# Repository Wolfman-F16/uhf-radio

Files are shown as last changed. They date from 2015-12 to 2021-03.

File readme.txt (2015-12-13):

This file is part of uhf-radio.
This project is hosted on github.com/Wolfman-F16
uhf-radio uses v-usb, which comes with its own GPL v2 license (see /usbdrv/license.txt).

    uhf-radio is free software: you can redistribute it and/or modify
    it under the terms of the GNU General Public License as published by
    the Free Software Foundation, either version 2 of the License, or
    any later version.

    uhf-radio is distributed in the hope that it will be useful,
    but WITHOUT ANY WARRANTY; without even the implied warranty of
    MERCHANTABILITY or FITNESS FOR A PARTICULAR PURPOSE.  See the
    GNU General Public License for more details.

    You should have received a copy of the GNU General Public License
    along with uhf-radio.  If not, see <http://www.gnu.org/licenses/>.

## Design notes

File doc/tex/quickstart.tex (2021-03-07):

\documentclass[12pt, a4paper]{report}

\usepackage[top=15mm, bottom=20mm, left=25mm, right=30mm]{geometry}
\usepackage[english]{babel}
\usepackage{verbatim}
\usepackage{lastpage}

\usepackage{longtable}
\usepackage{fancyhdr}
\usepackage{graphicx}
\usepackage{xcolor}

\fancypagestyle{plain} {
\renewcommand{\headrulewidth}{0pt}
	\fancyhf{}
	\fancyfoot[l]{
		\today
	}
	\fancyfoot[c]{
		v 1.2.0
	}
	\fancyfoot[r]{
		\thepage\slash \pageref*{LastPage}
	}
}

\usepackage[pdfauthor=Wolfman,pdftitle=UHF Radio,bookmarks]{hyperref}

%----------------------------------------------------------------  BEGIN OF DOCUMENT ---------------------------------------------------------------- 
\begin{document}

\title{UHF Electronics Quickstart Guide\\\large Electronics for UHF ARC-164 Airborne Radio Panel}
\author{Wolfgang ''Wolfman'' Engelhard }
\maketitle

% ---------------------------------------------------------------- history
\pagestyle {plain}

\section{Revision History}
\begin{itemize}
\item[1.0.3]
Page 5 updated
\item[1.1.0]
Pages 4,11,12 updated
\item[1.2.0]
Pages 11, 12 updated, minor clarifications in pages 13 to 15. Changed to \LaTeX
\end{itemize}•

% ---------------------------------------------------------------- disclaimer
\section{Disclamer}
This document is for information only. It may not be accurate, nor free of errors. It has been created with the best of my knowledge, but no liability is assumed for any damage caused by using this document or the devices described herein.

% ---------------------------------------------------------------- viperpits
\section{viperpits.org}
A lot of information is also available on the viperpits.org forum. If you want to know about the history of this development read the thread
\href{http://www.viperpits.org/smf/index.php?topic=5082.0}{viperpits.org UHF electronics}
(free registration required)

% ---------------------------------------------------------------- PARTLIST ---------------------------------------------------------------- 
\chapter{Partlist}
\begin{itemize}
\item[1x]
UHF Indication Board
\item[1x]
UHF Control Board
\item[1x]
UHF ARC-164 Panel
\item[1x]
5V\slash 1A power supply (an additional 5V\slash1.5A power supply if using backlight!)
\item[1x]
10pol flat wire connector cable
\item[1x]
2pol wire cable (already mounted)
\item[1x]
7-segment LED board
\item[1x]
Headphones or high ohm loudspeaker (not shown)
\end{itemize}•

\begin{figure}[h!tb]

\caption{Parts}
\end{figure}

% ---------------------------------------------------------------- Components
\section{Bill Of Material}
\framebox[\textwidth]{
\parbox{0.9\textwidth}{
Note:\newline I do not endorse buying from mouser, the intention is only to give reference.
}
}

\subsection{PCB}
The eagle\footnote{cadsoft.de} .brd files can be used to generate gerber files if your local PCB manufacturer does not accept eagle files.

% ---------------------------------------------------------------- Indication board partlist
\subsection{UHF Indication Board}
\begin{longtable}{ *{5}{| l } | }
\hline
\textbf{Article} & \textbf{Value} & \textbf{Type} & \textbf{\#} & \textbf{Mouser order number} \\
\hline
\endhead
ATMega8 & DIL-28 & IC & 1 & 556-ATMEGA8A-PU \\
Shift Register 595 & DIL-16 & IC & 8 & 511-M74HC595 \\
Quarz 16 Mhz & HC18U-V & Quarz & 1 & 815-ABL-16-B2 \\
IC-sockel (opt.) & 16 pol & Sockel & 8 & 517-4816-3000-CP \\
IC-sockel (opt.) & 28 pol & Sockel & 1 & 517-4828-3004-CP \\
LED yellow & 1206 & Led & 1 & 696-SML-LX1206YC \\
2V7 Z-Diode 1,3W & DO-204AL & Diode & 1 & 771-BZX79-C2V7133 \\
BC141 & TO-39 & Transistor & 1 & 511-BC141-16 \\
SMCC 10uH &  & Inductivity & 1 & 434-23-100 \\
100nF & RM5 & Capacitor & 4 & 80-C320C104K5R5CA \\
10nF & RM2.5 & Capacitor & 2 & 80-C315C103K5R5CA \\
1nF & RM2.5 & Capacitor & 1 & 80-C315C102K5R5CA \\
100pF & RM2.5 & Capacitor & 2 & 80-C315C101K5R5CA \\
22pF  & RM2.5 & Capacitor & 2 & 80-C315C220K5G5CA \\
150R & 805 & Resistor & 9 & 652-CR0805FX-1500ELF \\
8k2 & 805 & Resistor & 1 & 652-CR0805FX-8201ELF \\
180R & 1/4W & Resistor & 1 & 291-180-RC \\
560R & 1/4W & Resistor & 1 & 291-560-RC \\
10R & 5W & Resistor & 1 & 284-ACS5SW-10 \\
Powerplug & AK500/3 & Connector & 1 & 845-34.103 \\
Pinheader 10pol & 5x2 & Connector & 1 & 517-D2510-6002-AR \\
Pinheader 3pol & 3 pol & Connector & 1 & 855-M20-9730345 \\
Pinheader 8pol & 8 pol & Connector & 8 & 855-M20-9730846 \\
Poti 47k & RM2.54 & Poti & 1 & 652-3296Y-1-473LF \\
\hline
\caption {UHF Indication Board}
\end{longtable}

\framebox[\textwidth]{
\parbox{0.9\textwidth}{
Note:\par Instead of the Poti you could just as well mount a 3pol pinheader and connect any potentiometer with about the same resistor value.
}
}

% ---------------------------------------------------------------- Control board partlist
\subsection{UHF Control Board RP}
\begin{longtable}{ *{5}{| l } | }
\hline
\textbf{Article} & \textbf{Value} & \textbf{Type} & \textbf{\#} & \textbf{Mouser order number} \\
\hline
\endhead
ATMega8 & DIL-28 & IC & 1 & 556-ATMEGA8A-PU \\
22pF & RM2.5 & Capacitor & 2 & 80-C315C220K5G5CA \\
100pF & RM2.5 & Capacitor & 2 & 80-C315C101K5R5CA \\
10nF & RM2.5 & Capacitor & 2 & 80-C315C103K5R5CA \\
10nF & RM5 & Capacitor & 1 &  \\
100nF & RM5 & Capacitor & 2 & 80-C320C104K5R5CA \\
10uF El.Ca. & RM2.5 & Capacitor & 1 & 647-UST1H100MDD1TE \\
100uF El.Ca. & RM2.5 & Capacitor & 1 & 647-UVR1V101MED1TA \\
Audio Jack  & 3.5mm & Connector & 1 & 502-35RAPC4BH3 \\
Sockets 14pol & 14pol & Connector & 4 &  \\
Sockets 11pol & 11pol & Connector & 2 &  \\
Powerplug & A500/2 & Connector & 2 & 845-34.102 \\
Pinheader 3pol & 3 pol & Connector & 2 & 855-M20-9730345 \\
USB -B &  & Connector & 1 & 649-61729-0010BLF \\
Pinheader 6pol & 2x3 & Connector & 1 & 517-D2510-6002-AR \\
Pinheader 6pol & 3 pol & Connector & 2 & 855-M20-9730345 \\
3,3V Z-Diode Fast 0,5W & DO35 & Diode & 2 & 78-BZX55B3V3 \\
1N4148 & MINIMELF & Diode & 22 & 78-LL4148 \\
74HC154 & SO24W & IC & 1 & 771-74HC4515D \\
ATMega16 & DIL-40 & IC & 1 & 556-ATMEGA16A-PU \\
10uH & SMC & Inductivity & 1 & 434-23-100 \\
LED yellow & 1206 & Led & 1 & 696-SML-LX1206YC \\
16Mhz & HC18U-V & Quarz & 1 & 815-ABL-16-B2 \\
2k2 & 805 & Resistor & 1 & 652-CR0805FX-2201ELF \\
220R & 805 & Resistor & 1 & 652-CR0805FX-2200ELF \\
4k7 & 805 & Resistor & 1 & 652-CR0805FX-4701ELF \\
820R & 1/4W & Resistor & 1 & 291-820-RC \\
82R & 805 & Resistor & 2 & 652-CR0805FX-82R0ELF \\
8k2 & 805 & Resistor & 1 & 652-CR0805FX-8201ELF \\
150R & 805 & Resistor & 4 & 652-CR0805FX-1500ELF \\
IC-Sockel (opt.) & 40pol & Sockel & 1 & 517-4840-6000-CP \\
BC327 & TO-92 & Transistor & 1 & 512-BC32740BU \\
BC337 & TO-92 & Transistor & 1 & 512-BC33740BU \\
\hline
\caption {UHF Control Board RP}
\end {longtable}

% ---------------------------------------------------------------- other partlist
\subsection{Additional Components}
\begin{longtable}{ *{5}{| l } | }
\hline
\textbf{Article} & \textbf{Value} & \textbf{Type} & \textbf{\#} & \textbf{Mouser order number} \\
\hline
\endhead
ATMega8 & DIL-28 & IC & 1 & 556-ATMEGA8A-PU \\
Flat wire cable connector & AWG28 & Wire & 1 & 517-2M-BDBD-016-12 \\
Jumper wire & 2pol & Wire & 1 &  \\
7-Segment LED Com. Anode & RM2.54 & LED & 8 & 630-HDSP-7801-JK000 \\
Black wire 0.14mm² &  & Wire &  &  \\
Socket 8pol & RM2.54 & Connector & 8 &  \\
Prototype Board 160x100 & RM2.54 & PCB & 1 &  \\
Socket 5pol 5mm height & RM2.54 & Connector & 16 &  \\
\hline
\caption {Additional components}
\end {longtable}

% ----------------------------------------------------------------  ASSEMBLY ---------------------------------------------------------------- 
\chapter{Assembly}
% ---------------------------------------------------------------- wiring
\section{Wiring the 7-segment LED \emph{HDSP-7801-JK000}}

In case you use the 7-Segment LED Avago \emph{HDSP-7801-JK000}, you can use the following table to wire the devices.

\begin{table}[ht]
\centering
\begin{tabular}{ *{3}{| l } | }
\hline
\textbf{UHF Indication Board Pin} & \textbf{Segment} & \textbf{HDSP-7801-JK000 Pin} \\
\hline
1 (lilac) & a & 10 \\
\hline
2 (blue) & b & 9 \\
\hline
3 (green) & c & 8 \\
\hline
4 (yellow) & d & 5 \\
\hline
5 (orange) & e & 4 \\
\hline
6 (red) & f & 2 \\
\hline
7 (brown) & g & 3 \\
\hline
8 (black) & DP & 7 \\
\hline
Common Anode &   & 6 \&{} 1 \\
\hline
\end{tabular}
\caption {Wiring}
\end {table}
\label{Table4}

\begin{figure}[h!tb]
\centering

\caption{7-Segment LED layout}
\end{figure}

There are ready made connectors\footnote{\parbox{105mm}{\href{http://www.reichelt.de/Platinen-Steckverbinder/PS-25-8G-WS/3//index.html?ACTION=3\&GROUPID=5216\&ARTICLE=14831\&SHOW=1\&START=0\&OFFSET=500\&}{reichelt.de PS-25-8G-WS}}} available that use colored wires. These match the colors given for the UHF Indication Board Pin in Table \ref{Table4}. 

Connect all Common Anode pins to a common (preferably red) wire.

The LEDs should be soldered to small prototype boards that fit into the tiny space of the UHF panel. Sockets do not provide reliable contact.
Mount the 7-Segment LED Board to the UHF ARC-164 Panel. M2.5 screws fit through the UHF panel holes.

% ---------------------------------------------------------------- Board assembly
\section{Assembly of UHF Control Board and UHF Indication Board}
\emph{TODO}

\emph{
Note: \\ The preferred  way to mount the boards would be in a 90 degree angle to the UHF panel. This allows use of short wires for all connections. A casing, like the real panel could be build to mount the boards with spacers to the sidewalls.
}

% ---------------------------------------------------------------- CONNECTIONS ---------------------------------------------------------------- 
\chapter{Connections}
% ---------------------------------------------------------------- 
\section{If you have only the UHF Indication Board}
\begin{enumerate}
\item
Connect the UHF Indication Board with the 5V Powersupply. The polarity is printed on the PCB.
\item
Connect the 7-Segment LED Board to the UHF Indication Board.
\end{enumerate}•

\begin{figure}[h!tb]
\centering

\caption{Pin 1}
\end{figure}

The UHF Indication Board Pin 1 is at the same position for all connectors.
The common anode wire is connected to the power plug labeled "PWM".

The 7-seg. LEDs are assigned as shown in figure \ref{fig:ledConn}
\begin{figure}[h!]
\centering

\caption{PCB to Display Connection}
\label{fig:ledConn}
\end{figure}

% ---------------------------------------------------------------- 
\section{If you have both the UHF Indication Board and the UHF Control Board}

\begin{enumerate}
\item
Do the connections for the UHF Indication Board as instructed in the previous chapter.
\item
Connect the Volume knob pinheader to a potentiometer with the 2pol wire cable. 

\framebox[\textwidth]{
\parbox{0.9\textwidth}{
Note: \newline
The UHF Control Board can use the Volume knob of the UHF ARC-164 Panel to adjust volume.
Use the 2pol wire cable to connect the Volume knob pinheader to the audio volume pinheader of the UHF Control Board. (see figure \ref{fig:volPoti})
}
}

\begin{figure}[h!t]
\centering

\caption{Volume Potentiometer Connection}
\label{fig:volPoti}
\end{figure}

\item
Connect the UHF Control Board to the UHF ARC-164 Panel. The wiring is 1:1 when the board faces the panel (see also labeling J1 and J2 on both board and panel).

\begin{figure}[h!t]
\centering

\caption{Control Board Connection}
\label{fig:brdConn}
\end{figure}

\item
Connect the UHF Indication Board and the UHF Control Board with the 10pol flat wire cable.

\item
Connect Headphones to the UHF Control Board.
\item
UHF panel backlight power supply
The powersupply for the UHF Panel backlight is connected to the UHF Control Board (The Power Plug labelled "Backlight" in figure \ref{fig:volPoti}).

\item
UHF Control Board power supply, USB not connected
The power plug "Power Supply" for the UHF Control Board (see figure \ref{fig:volPoti}) should be left unconnected. The board receives its power through the UHF Indication Board.

\framebox[\textwidth]{
\parbox{0.9\textwidth}{\large\color{red}
\textsc{Warning:}\newline
Do \textsc{not} connect the UHF Control Board to the USB port for power supply!
Always connect the UHF Indication Board with a power supply!
}
}

\item
UHF Control Board power supply, USB connected
Connect a standard USB-B cable to the UHF Control Board.
The USB port provides power for the UHF Control Board, to avoid damaging your USB port, break the 1st wire of the 10pol flat wire cable. The power plug "Power supply" is for debugging purposes only.

\end{enumerate}•

% ---------------------------------------------------------------- TTL 
\section{If you have a TTL USART device}
Both boards have a serial interface operating on TTL voltage. The transmit pin is labeled "T", The receive pin is labeled "R" and the ground pin is labeld "G". Connect a RS232-TTL or USB-TTL converter for accessing terminal operations. The baud rate is 38400.

% ---------------------------------------------------------------- OPERATION ----------------------------------------------------------------
\chapter{Operation}
% ---------------------------------------------------------------- Switch on
\section{Power On}
The LEDs should display a test pattern for about a second, then show a channel number and a frequency.
The status LED on the UHF Indication Board should be briefly on.
The UHF Indication Board has a potentiometer to adjust brightness. Adjust as preferred.

% ---------------------------------------------------------------- usage
\section {Usage}
The operation of the UHF radio is documented in this PDF file.

\href{http://mayprinting.com/TSB/data/comm/arc-164.pdf}{http://mayprinting.com/TSB/data/comm/arc-164.pdf}\footnote{This link does not work anymore.}

\noindent
The TSS/RSG frequency is 310.425. Use this frequency to get a Tone.

% ---------------------------------------------------------------- USB
\section{USB Keyboard}
The UHF Control Board operates as a USB keyboard.

The Squelch switch in position ON suppresses sending keystrokes, so make sure it is in the correct position.

A prototype USB vendor and product ID are used, so use at your own risk!
The following switches send key strokes

\begin{longtable}{ *{2}{| l } | }
\hline
\textbf{Operator} & \textbf{Key} \\
\hline
\endhead
Mode Selector OFF & SHF ALT ENTER \\
Mode Selector MAIN & ALT CTRL ENTER \\
Mode Selector BOTH & SHF ALT CTRL ENTER \\
Mode Selector ADF & SHF CTRL Z \\
MPG MNL & SHF ALT CTRL X \\
MPG PRESET & SHF CTRL C \\
MPG GRD & SHF ALT C \\
CHAN INC & SHF ALT S \\
CHAN DEC & ALT CTRL S \\
FREQ 1 2 & SHF ALT D \\
FREQ 1 3 & ALT CTRL D \\
FREQ 1 A & SHF CTRL D \\
FREQ 2 0 & SHF ALT CTRL D \\
FREQ 2 1 & SHF CTRL F \\
FREQ 2 2 & SHF ALT F \\
FREQ 2 3 & ALT CTRL F \\
FREQ 2 4 & SHF ALT CTRL M \\
FREQ 2 5 & SHF CTRL G \\
FREQ 2 6 & SHF ALT G \\
FREQ 2 7 & ALT CTRL G \\
FREQ 2 8 & SHF ALT CTRL G \\
FREQ 2 9 & SHF CTRL H \\ 
FREQ 3 0 & SHF ALT H \\
FREQ 3 1 & ALT CTRL H \\
FREQ 3 2 & SHF ALT CTRL H \\
FREQ 3 3 & SHF CTRL J \\
FREQ 3 4 & SHF ALT J \\
FREQ 3 5 & ALT CTRL J \\
FREQ 3 6 & SHF ALT CTRL J \\
FREQ 3 7 & SHF CTRL K \\
FREQ 3 8 & SHF ALT K \\ 
FREQ 3 9 & ALT CTRL K \\
FREQ 4 0 & SHF ALT CTRL K \\
FREQ 4 1 & SHF CTRL L \\
FREQ 4 2 & SHF ALT L \\
FREQ 4 3 & ALT CTRL L \\
FREQ 4 4 & SHF ALT CTRL L \\
FREQ 4 5 & SHF CTRL ; \\
FREQ 4 6 & SHF ALT ; \\
FREQ 4 7 & ALT CTRL ; \\
FREQ 4 8 & SHF ALT CTRL ; \\
FREQ 4 9 & SHF CTRL ' \\
FREQ 5 00 & SHF ALT ' \\
FREQ 5 25 & ALT CTRL ` \\
FREQ 5 50 & SHF ALT CTRL ` \\
FREQ 5 75 & SHF CTRL ENTER \\
\hline
\caption {Key Assignment}
\end {longtable}
\begin{comment}
These are not supported yet in source code and Falcon BMS
LOAD & SHF CTRL S \\
STATUS & SHF ALT CTRL S \\
Zero On & ALT CTRL A \\
Zero Off & SHF ALT CTRL A \\
Squelch On & SHF ALT X \\
Squelch Off & ALT CTRL X \\
Tone T & SHF ALT Z \\
Tone TONE & ALT CTRL Z \\
CH Vol Inc & SHF ALT CTRL Z \\
CH Vol Dec & SHF CTRL X \\
TEST & SHF ALT . \\
\end{comment}

% ---------------------------------------------------------------- shared  mem
\section {Connecting to Falcon BMS Shared Memory}

With firmware version 23 an newer (see chapter Operation on how to check the version), the UHF radio supports synchronising with the shared memory. A shared memory reader is required to establish the data transfer and is available at github\footnote{github.com/Wolfman-F16/uhfRadioUsbSharedMemReader}. 
To allow data transfer to a USB Keyboard (that is what the UHF radio basically is for a Windows OS), installation of a filter is required. 
The software to do so is available at \href{http://sourceforge.net/projects/libusb-win32/}{libusb-win32}.
Type \begin{quote}\emph{install-filter install –device=USBVid\_16c0.Pid\_27db.Rev\_0100} \end{quote} on the commandline. Or use the \emph{install-filter-gui.exe} to do the same. This must be done only a single time.
Start the commandline tool \emph{uhfRadio.exe} and data will be sent, once the shared memory is available.

\framebox[\textwidth]{
\parbox{0.9\textwidth}{
Note: \newline
Before ramp start, set the UHF radio rotary switches to channel 6 and frequency 225.000
}
}

\framebox[\textwidth]{
\parbox{0.9\textwidth}{
Note: \newline
During Falcon BMS ramp/taxi/takeoff loading screen, the channel and frequency often show wierd numbers for a brief time.
}
}

\framebox[\textwidth]{
\parbox{0.9\textwidth}{
Note: \newline
If channel or frequency is out of sync, use the squelch switch to suppress sending key strokes.
}
}

% ---------------------------------------------------------------- MAINTENANCE ----------------------------------------------------------------
\chapter{Maintenance}
% ---------------------------------------------------------------- Firmware
\section{Firmware Version}
The software version of the UHF Control Board can be displayed by switching to ADF and switching the T-Tone switch to T.

The current firmware version as of writing this document is v28.

\section{Firmware Update}
The UHF Control Board supports firmware update via USB. Before being able to use the USB firmware update, the USB bootloader\footnote{\href{}{github.com/Wolfman-F16/usbBootloader}} has to be flashed onto the UHF Control Board microcontroller.
To put the UHF Control Board in USB bootloader mode, 
\begin{enumerate}
\item
disconnect the UHF radio from power (incl. USB)
\item
 switch to ADF
 \item
 power up the UHF radio again.
\end{enumerate}•
Use the commandline tool \emph{avrusbboot.exe}\footnote{\href{}{github.com/Wolfman-F16/usbBootloaderCommander}} to upload the new firmware.
When the firmware upload is complete, put the UHF radio in normal operating mode by
\begin{enumerate}
\item
 disconnect the UHF radio from power (incl. USB)
 \item
switch to UHF OFF
\item
power up the UHF radio again.
\end{enumerate}•

% ---------------------------------------------------------------- Known Issues
\section{Known Issues}
\begin{itemize}
\item[]
TOD update and initiation of individual TOD not implemented, because there is no other radio that can be queried for a valid Tone signal (see also arc-164.pdf: 4-20 to 4-22).
\item[]
The FMT CHG text is not displayed after 5 seconds of inactivity in FMT.CHG mode.
\item[]
No interface to Falcon 4.0, Falcon 4 Allied Force or OpenFalcon4.7 is implemented, because non of them support UHF ARC-164 radio operations. 
However, Falcon BMS 4.32 provides limited support of UHF ARC-164 radio operations, extraction of display data is supported since Falcon BMS 4.33.
\item[]
The UHF panel volume knob cannot be used to control anything in Falcon BMS.
\item[]
The UHF Indication Board, when operated stand alone, might always show the LED test. Connect 5V to the pin SS (6) to solve this.
\item[]
If you think you found an error in this document or the software, please post at this forum thread
\href{http://www.viperpits.org/smf/index.php?topic=5082.0}{viperpits.org UHF electronics}
But remember the RTFM rule, so you might want to check the \emph{arc164.pdf} file thoroughly first.
\end{itemize}•

\tableofcontents

\end{document}

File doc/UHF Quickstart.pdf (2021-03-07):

# UHF Electronics Quickstart Guide

### Electronics for UHF ARC-164 Airborne Radio Panel

### Wolfgang ”Wolfman” Engelhard

### March 7, 2021

## 0.1 Revision History

1.0.3 Page 5 updated

1.1.0 Pages 4,11,12 updated

1.2.0 Pages 11, 12 updated, minor clarifications in pages 13 to 15. Changed to LATEX

## 0.2 Disclamer

This document is for information only. It may not be accurate, nor free of errors. It has been created with the best of my knowledge, but no liability is assumed for any damage caused by using this document or the devices described herein.

## 0.3 viperpits.org

A lot of information is also available on the viperpits.org forum. If you want to know about the history of this development read the thread viperpits.org UHF electronics (http://www.viperpits.org/smf/index.php?topic=5082.0) (free registration required)

March 7, 2021 | v 1.2.0 | 1/16

# Chapter 1

# Partlist

1x UHF Indication Board

1x UHF Control Board

1x UHF ARC-164 Panel

1x 5V/1A power supply (an additional 5V/1.5A power supply if using backlight!)

1x 10pol flat wire connector cable

1x 2pol wire cable (already mounted)

1x 7-segment LED board

1x Headphones or high ohm loudspeaker (not shown)

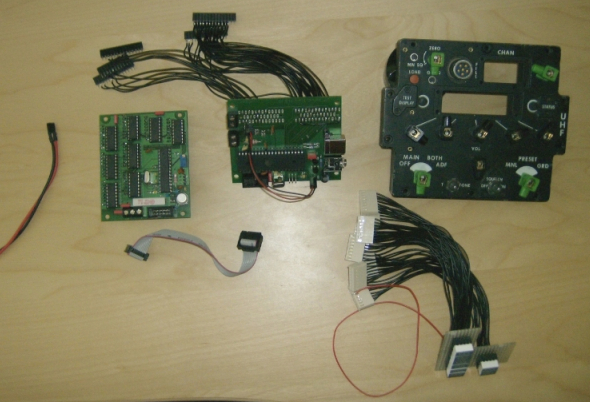
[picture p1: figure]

Figure 1.1: Parts

## 1.1 Bill Of Material

Note:
I do not endorse buying from mouser, the intention is only to give reference.

### 1.1.1 PCB

The eagle¹
.brd files can be used to generate gerber files if your local PCB manufacturer does not accept eagle files.

### 1.1.2 UHF Indication Board

Article | Value | Type | # | Mouser order number
ATMega8 | DIL-28 | IC | 1 | 556-ATMEGA8A-PU
Shift Register 595 | DIL-16 | IC | 8 | 511-M74HC595
Quarz 16 Mhz | HC18U-V | Quarz | 1 | 815-ABL-16-B2
IC-sockel (opt.) | 16 pol | Sockel | 8 | 517-4816-3000-CP
IC-sockel (opt.) | 28 pol | Sockel | 1 | 517-4828-3004-CP
LED yellow | 1206 | Led | 1 | 696-SML-LX1206YC
2V7 Z-Diode 1,3W | DO-204AL | Diode | 1 | 771-BZX79-C2V7133
BC141 | TO-39 | Transistor | 1 | 511-BC141-16
SMCC 10uH | | Inductivity | 1 | 434-23-100
100nF | RM5 | Capacitor | 4 | 80-C320C104K5R5CA
10nF | RM2.5 | Capacitor | 2 | 80-C315C103K5R5CA
1nF | RM2.5 | Capacitor | 1 | 80-C315C102K5R5CA
100pF | RM2.5 | Capacitor | 2 | 80-C315C101K5R5CA
22pF | RM2.5 | Capacitor | 2 | 80-C315C220K5G5CA
150R | 805 | Resistor | 9 | 652-CR0805FX-1500ELF
8k2 | 805 | Resistor | 1 | 652-CR0805FX-8201ELF
180R | 1/4W | Resistor | 1 | 291-180-RC
560R | 1/4W | Resistor | 1 | 291-560-RC
10R | 5W | Resistor | 1 | 284-ACS5SW-10
Powerplug | AK500/3 | Connector | 1 | 845-34.103
Pinheader 10pol | 5x2 | Connector | 1 | 517-D2510-6002-AR
Pinheader 3pol | 3 pol | Connector | 1 | 855-M20-9730345
Pinheader 8pol | 8 pol | Connector | 8 | 855-M20-9730846
Poti 47k | RM2.54 | Poti | 1 | 652-3296Y-1-473LF
Table 1.1: UHF Indication Board

Note:
Instead of the Poti you could just as well mount a 3pol pinheader and connect any potentiometer with about the same resistor value.

### 1.1.3 UHF Control Board RP

Article | Value | Type | # | Mouser order number
ATMega8 | DIL-28 | IC | 1 | 556-ATMEGA8A-PU
22pF | RM2.5 | Capacitor | 2 | 80-C315C220K5G5CA
100pF | RM2.5 | Capacitor | 2 | 80-C315C101K5R5CA

1
cadsoft.de

Article | Value | Type | # | Mouser order number
10nF | RM2.5 | Capacitor | 2 | 80-C315C103K5R5CA
10nF | RM5 | Capacitor | 1
100nF | RM5 | Capacitor | 2 | 80-C320C104K5R5CA
10uF El.Ca. | RM2.5 | Capacitor | 1 | 647-UST1H100MDD1TE
100uF El.Ca. | RM2.5 | Capacitor | 1 | 647-UVR1V101MED1TA
Audio Jack | 3.5mm | Connector | 1 | 502-35RAPC4BH3
Sockets 14pol | 14pol | Connector | 4
Sockets 11pol | 11pol | Connector | 2
Powerplug | A500/2 | Connector | 2 | 845-34.102
Pinheader 3pol | 3 pol | Connector | 2 | 855-M20-9730345
USB -B | | Connector | 1 | 649-61729-0010BLF
Pinheader 6pol | 2x3 | Connector | 1 | 517-D2510-6002-AR
Pinheader 6pol | 3 pol | Connector | 2 | 855-M20-9730345
3,3V Z-Diode Fast 0,5W | DO35 | Diode | 2 | 78-BZX55B3V3
1N4148 | MINIMELF | Diode | 22 | 78-LL4148
74HC154 | SO24W | IC | 1 | 771-74HC4515D
ATMega16 | DIL-40 | IC | 1 | 556-ATMEGA16A-PU
10uH | SMC | Inductivity | 1 | 434-23-100
LED yellow | 1206 | Led | 1 | 696-SML-LX1206YC
16Mhz | HC18U-V | Quarz | 1 | 815-ABL-16-B2
2k2 | 805 | Resistor | 1 | 652-CR0805FX-2201ELF
220R | 805 | Resistor | 1 | 652-CR0805FX-2200ELF
4k7 | 805 | Resistor | 1 | 652-CR0805FX-4701ELF
820R | 1/4W | Resistor | 1 | 291-820-RC
82R | 805 | Resistor | 2 | 652-CR0805FX-82R0ELF
8k2 | 805 | Resistor | 1 | 652-CR0805FX-8201ELF
150R | 805 | Resistor | 4 | 652-CR0805FX-1500ELF
IC-Sockel (opt.) | 40pol | Sockel | 1 | 517-4840-6000-CP
BC327 | TO-92 | Transistor | 1 | 512-BC32740BU
BC337 | TO-92 | Transistor | 1 | 512-BC33740BU
Table 1.2: UHF Control Board RP

### 1.1.4 Additional Components

Article | Value | Type | # | Mouser order number
ATMega8 Flat wire cable connector Jumper wire 7-Segment LED Com. Anode Black wire 0.14mm Socket 8pol Prototype Board 160x100 Socket 5pol 5mm height | DIL-28 AWG28 2pol RM2.54 RM2.54 RM2.54 RM2.54 | IC Wire Wire LED Wire Connector PCB Connector | 1 1 1 8 8 1 16 | 556-ATMEGA8A-PU 517-2M-BDBD-016-12 630-HDSP-7801-JK000

Table 1.3: Additional components

# Chapter 2

# Assembly

## 2.1 Wiring the 7-segment LED HDSP-7801-JK000

In case you use the 7-Segment LED Avago HDSP-7801-JK000, you can use the following table to wire the devices.

UHF Indication Board Pin | Segment | HDSP-7801-JK000 Pin
1 (lilac) | a | 10
2 (blue) | b | 9
3 (green) | c | 8
4 (yellow) | d | 5
5 (orange) | e | 4
6 (red) | f | 2
7 (brown) | g | 3
8 (black) | DP | 7
Common Anode | | 6 & 1

Table 2.1: Wiring

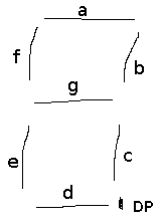
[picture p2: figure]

Figure 2.1: 7-Segment LED layout

There are ready made connectors¹ available that use colored wires. These match the colors given for the UHF Indication Board Pin in Table 2.1.
Connect all Common Anode pins to a common (preferably red) wire.
The LEDs should be soldered to small prototype boards that fit into the tiny space of the UHF panel. Sockets do not provide reliable contact. Mount the 7-Segment LED Board to the UHF ARC-164 Panel. M2.5 screws fit through the UHF panel holes.

1
reichelt.de PS-25-8G-WS (http://www.reichelt.de/Platinen-Steckverbinder/PS-25-8G-WS/3//index.html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)

## 2.2 Assembly of UHF Control Board and UHF Indication Board

TODO
Note:
The preferred way to mount the boards would be in a 90 degree angle to the UHF panel. This allows use of short wires for all connections. A casing, like the real panel could be build to mount the boards with spacers to the sidewalls.

# Chapter 3

# Connections

## 3.1 If you have only the UHF Indication Board

1. Connect the UHF Indication Board with the 5V Powersupply. The polarity is printed on the PCB.
2. Connect the 7-Segment LED Board to the UHF Indication Board.

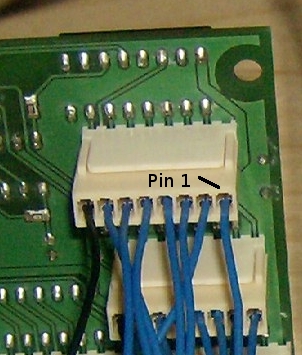
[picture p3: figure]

Figure 3.1: Pin 1

The UHF Indication Board Pin 1 is at the same position for all connectors. The common anode wire is connected to the power plug labeled ”PWM”.
The 7-seg. LEDs are assigned as shown in figure 3.2

## 3.2 If you have both the UHF Indication Board and the UHF Control Board

1. Do the connections for the UHF Indication Board as instructed in the previous chapter.
2. Connect the Volume knob pinheader to a potentiometer with the 2pol wire cable.

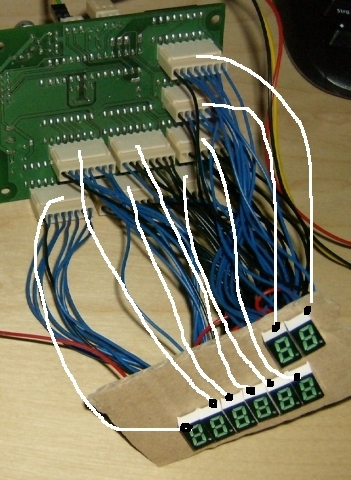
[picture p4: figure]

Figure 3.2: PCB to Display Connection

Note:
The UHF Control Board can use the Volume knob of the UHF ARC-164 Panel to adjust volume. Use the 2pol wire cable to connect the Volume knob pinheader to the audio volume pinheader of the UHF Control Board. (see figure 3.3)
3. Connect the UHF Control Board to the UHF ARC-164 Panel. The wiring is 1:1 when the board faces the panel (see also labeling J1 and J2 on both board and panel).
4. Connect the UHF Indication Board and the UHF Control Board with the 10pol flat wire cable.
5. Connect Headphones to the UHF Control Board.
6. UHF panel backlight power supply The powersupply for the UHF Panel backlight

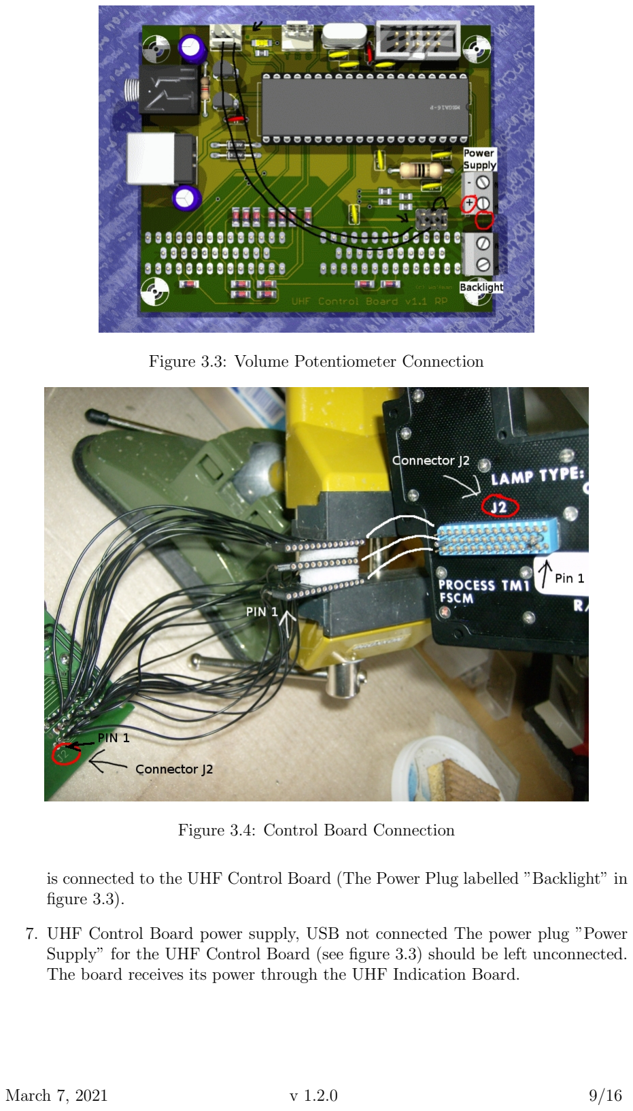
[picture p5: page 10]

Figure 3.3: Volume Potentiometer Connection

Figure 3.4: Control Board Connection

is connected to the UHF Control Board (The Power Plug labelled ”Backlight” in figure 3.3).

7. UHF Control Board power supply, USB not connected The power plug ”Power Supply” for the UHF Control Board (see figure 3.3) should be left unconnected. The board receives its power through the UHF Indication Board.

Warning:

### Do not connect the UHF Control Board to the USB port for power supply! Always connect the UHF Indication Board with a power supply!

8. UHF Control Board power supply, USB connected Connect a standard USB-B cable to the UHF Control Board. The USB port provides power for the UHF Control Board, to avoid damaging your USB port, break the 1st wire of the 10pol flat wire cable. The power plug ”Power supply” is for debugging purposes only.

## 3.3 If you have a TTL USART device

Both boards have a serial interface operating on TTL voltage. The transmit pin is labeled ”T”, The receive pin is labeled ”R” and the ground pin is labeld ”G”. Connect a RS232-TTL or USB-TTL converter for accessing terminal operations. The baud rate is 38400.

# Chapter 4

# Operation

## 4.1 Power On

The LEDs should display a test pattern for about a second, then show a channel number and a frequency. The status LED on the UHF Indication Board should be briefly on. The UHF Indication Board has a potentiometer to adjust brightness. Adjust as preferred.

## 4.2 Usage

The operation of the UHF radio is documented in this PDF file. http://mayprinting.com/TSB/data/comm/arc-164.pdf¹
The TSS/RSG frequency is 310.425. Use this frequency to get a Tone.

## 4.3 USB Keyboard

The UHF Control Board operates as a USB keyboard.
The Squelch switch in position ON suppresses sending keystrokes, so make sure it is in the correct position.
A prototype USB vendor and product ID are used, so use at your own risk! The following switches send key strokes
Operator | Key
Mode Selector OFF | SHF ALT ENTER
Mode Selector MAIN | ALT CTRL ENTER
Mode Selector BOTH | SHF ALT CTRL ENTER
Mode Selector ADF | SHF CTRL Z
MPG MNL | SHF ALT CTRL X
MPG PRESET | SHF CTRL C
MPG GRD | SHF ALT C
CHAN INC | SHF ALT S
CHAN DEC | ALT CTRL S
FREQ 1 2 | SHF ALT D
FREQ 1 3 | ALT CTRL D
FREQ 1 A | SHF CTRL D
FREQ 2 0 | SHF ALT CTRL D
FREQ 2 1 | SHF CTRL F

1This link does not work anymore.

Operator | Key
FREQ 2 2 | SHF ALT F
FREQ 2 3 | ALT CTRL F
FREQ 2 4 | SHF ALT CTRL M
FREQ 2 5 | SHF CTRL G
FREQ 2 6 | SHF ALT G
FREQ 2 7 | ALT CTRL G
FREQ 2 8 | SHF ALT CTRL G
FREQ 2 9 | SHF CTRL H
FREQ 3 0 | SHF ALT H
FREQ 3 1 | ALT CTRL H
FREQ 3 2 | SHF ALT CTRL H
FREQ 3 3 | SHF CTRL J
FREQ 3 4 | SHF ALT J
FREQ 3 5 | ALT CTRL J
FREQ 3 6 | SHF ALT CTRL J
FREQ 3 7 | SHF CTRL K
FREQ 3 8 | SHF ALT K
FREQ 3 9 | ALT CTRL K
FREQ 4 0 | SHF ALT CTRL K
FREQ 4 1 | SHF CTRL L
FREQ 4 2 | SHF ALT L
FREQ 4 3 | ALT CTRL L
FREQ 4 4 | SHF ALT CTRL L
FREQ 4 5 | SHF CTRL ;
FREQ 4 6 | SHF ALT ;
FREQ 4 7 | ALT CTRL ;
FREQ 4 8 | SHF ALT CTRL ;
FREQ 4 9 | SHF CTRL ’
FREQ 5 00 | SHF ALT ’
FREQ 5 25 | ALT CTRL ‘
FREQ 5 50 | SHF ALT CTRL ‘
FREQ 5 75 | SHF CTRL ENTER
Table 4.1: Key Assignment

## 4.4 Connecting to Falcon BMS Shared Memory

With firmware version 23 an newer (see chapter Operation on how to check the version), the UHF radio supports synchronising with the shared memory. A shared memory reader is required to establish the data transfer and is available at github²
. To allow
data transfer to a USB Keyboard (that is what the UHF radio basically is for a Windows OS), installation of a filter is required. The software to do so is available at libusbwin32. (http://sourceforge.net/projects/libusb-win32/) Type

install-filter install device=USBVid 16c0.Pid 27db.Rev 0100

on the commandline. Or use the install-filter-gui.exe to do the same. This must be done only a single time. Start the commandline tool uhfRadio.exe and data will be sent, once the shared memory is available.

2github.com/Wolfman-F16/uhfRadioUsbSharedMemReader

Note:
Before ramp start, set the UHF radio rotary switches to channel 6 and frequency 225.000
Note:
During Falcon BMS ramp/taxi/takeoff loading screen, the channel and frequency often show wierd numbers for a brief time.

Note:
If channel or frequency is out of sync, use the squelch switch to suppress sending key strokes.

# Chapter 5

# Maintenance

## 5.1 Firmware Version

The software version of the UHF Control Board can be displayed by switching to ADF and switching the T-Tone switch to T.
The current firmware version as of writing this document is v28.

## 5.2 Firmware Update

The UHF Control Board supports firmware update via USB. Before being able to use the USB firmware update, the USB bootloader¹ has to be flashed onto the UHF Control Board microcontroller. To put the UHF Control Board in USB bootloader mode,

1. disconnect the UHF radio from power (incl. USB)
2. switch to ADF
3. power up the UHF radio again.

Use the commandline tool avrusbboot.exe²
to upload the new firmware. When the firmware upload is complete, put the UHF radio in normal operating mode by
1. disconnect the UHF radio from power (incl. USB)
2. switch to UHF OFF
3. power up the UHF radio again.

## 5.3 Known Issues

TOD update and initiation of individual TOD not implemented, because there is no other radio that can be queried for a valid Tone signal (see also arc-164.pdf: 4-20 to 4-22).

The FMT CHG text is not displayed after 5 seconds of inactivity in FMT.CHG mode.

1github.com/Wolfman-F16/usbBootloader
2github.com/Wolfman-F16/usbBootloaderCommander

No interface to Falcon 4.0, Falcon 4 Allied Force or OpenFalcon4.7 is implemented, because non of them support UHF ARC-164 radio operations. However, Falcon BMS 4.32 provides limited support of UHF ARC-164 radio operations, extraction of display data is supported since Falcon BMS 4.33.

The UHF panel volume knob cannot be used to control anything in Falcon BMS.

The UHF Indication Board, when operated stand alone, might always show the LED test. Connect 5V to the pin SS (6) to solve this.

If you think you found an error in this document or the software, please post at this forum thread viperpits.org UHF electronics (http://www.viperpits.org/smf/index.php?topic=5082.0) But remember the RTFM rule, so you might want to check the arc164.pdf file thoroughly first.

# Contents

1 Partlist | 2
2 Assembly | 5
3 Connections | 7
3.2 If you have both the UHF Indication Board and the UHF Control Board | 7
4 Operation | 11
5 Maintenance | 14

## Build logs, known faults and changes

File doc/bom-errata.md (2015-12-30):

#quickstart.1.0.3.pdf#

##Errata##

none

##Equivalent parts##

BC141-16 -> 2N2102

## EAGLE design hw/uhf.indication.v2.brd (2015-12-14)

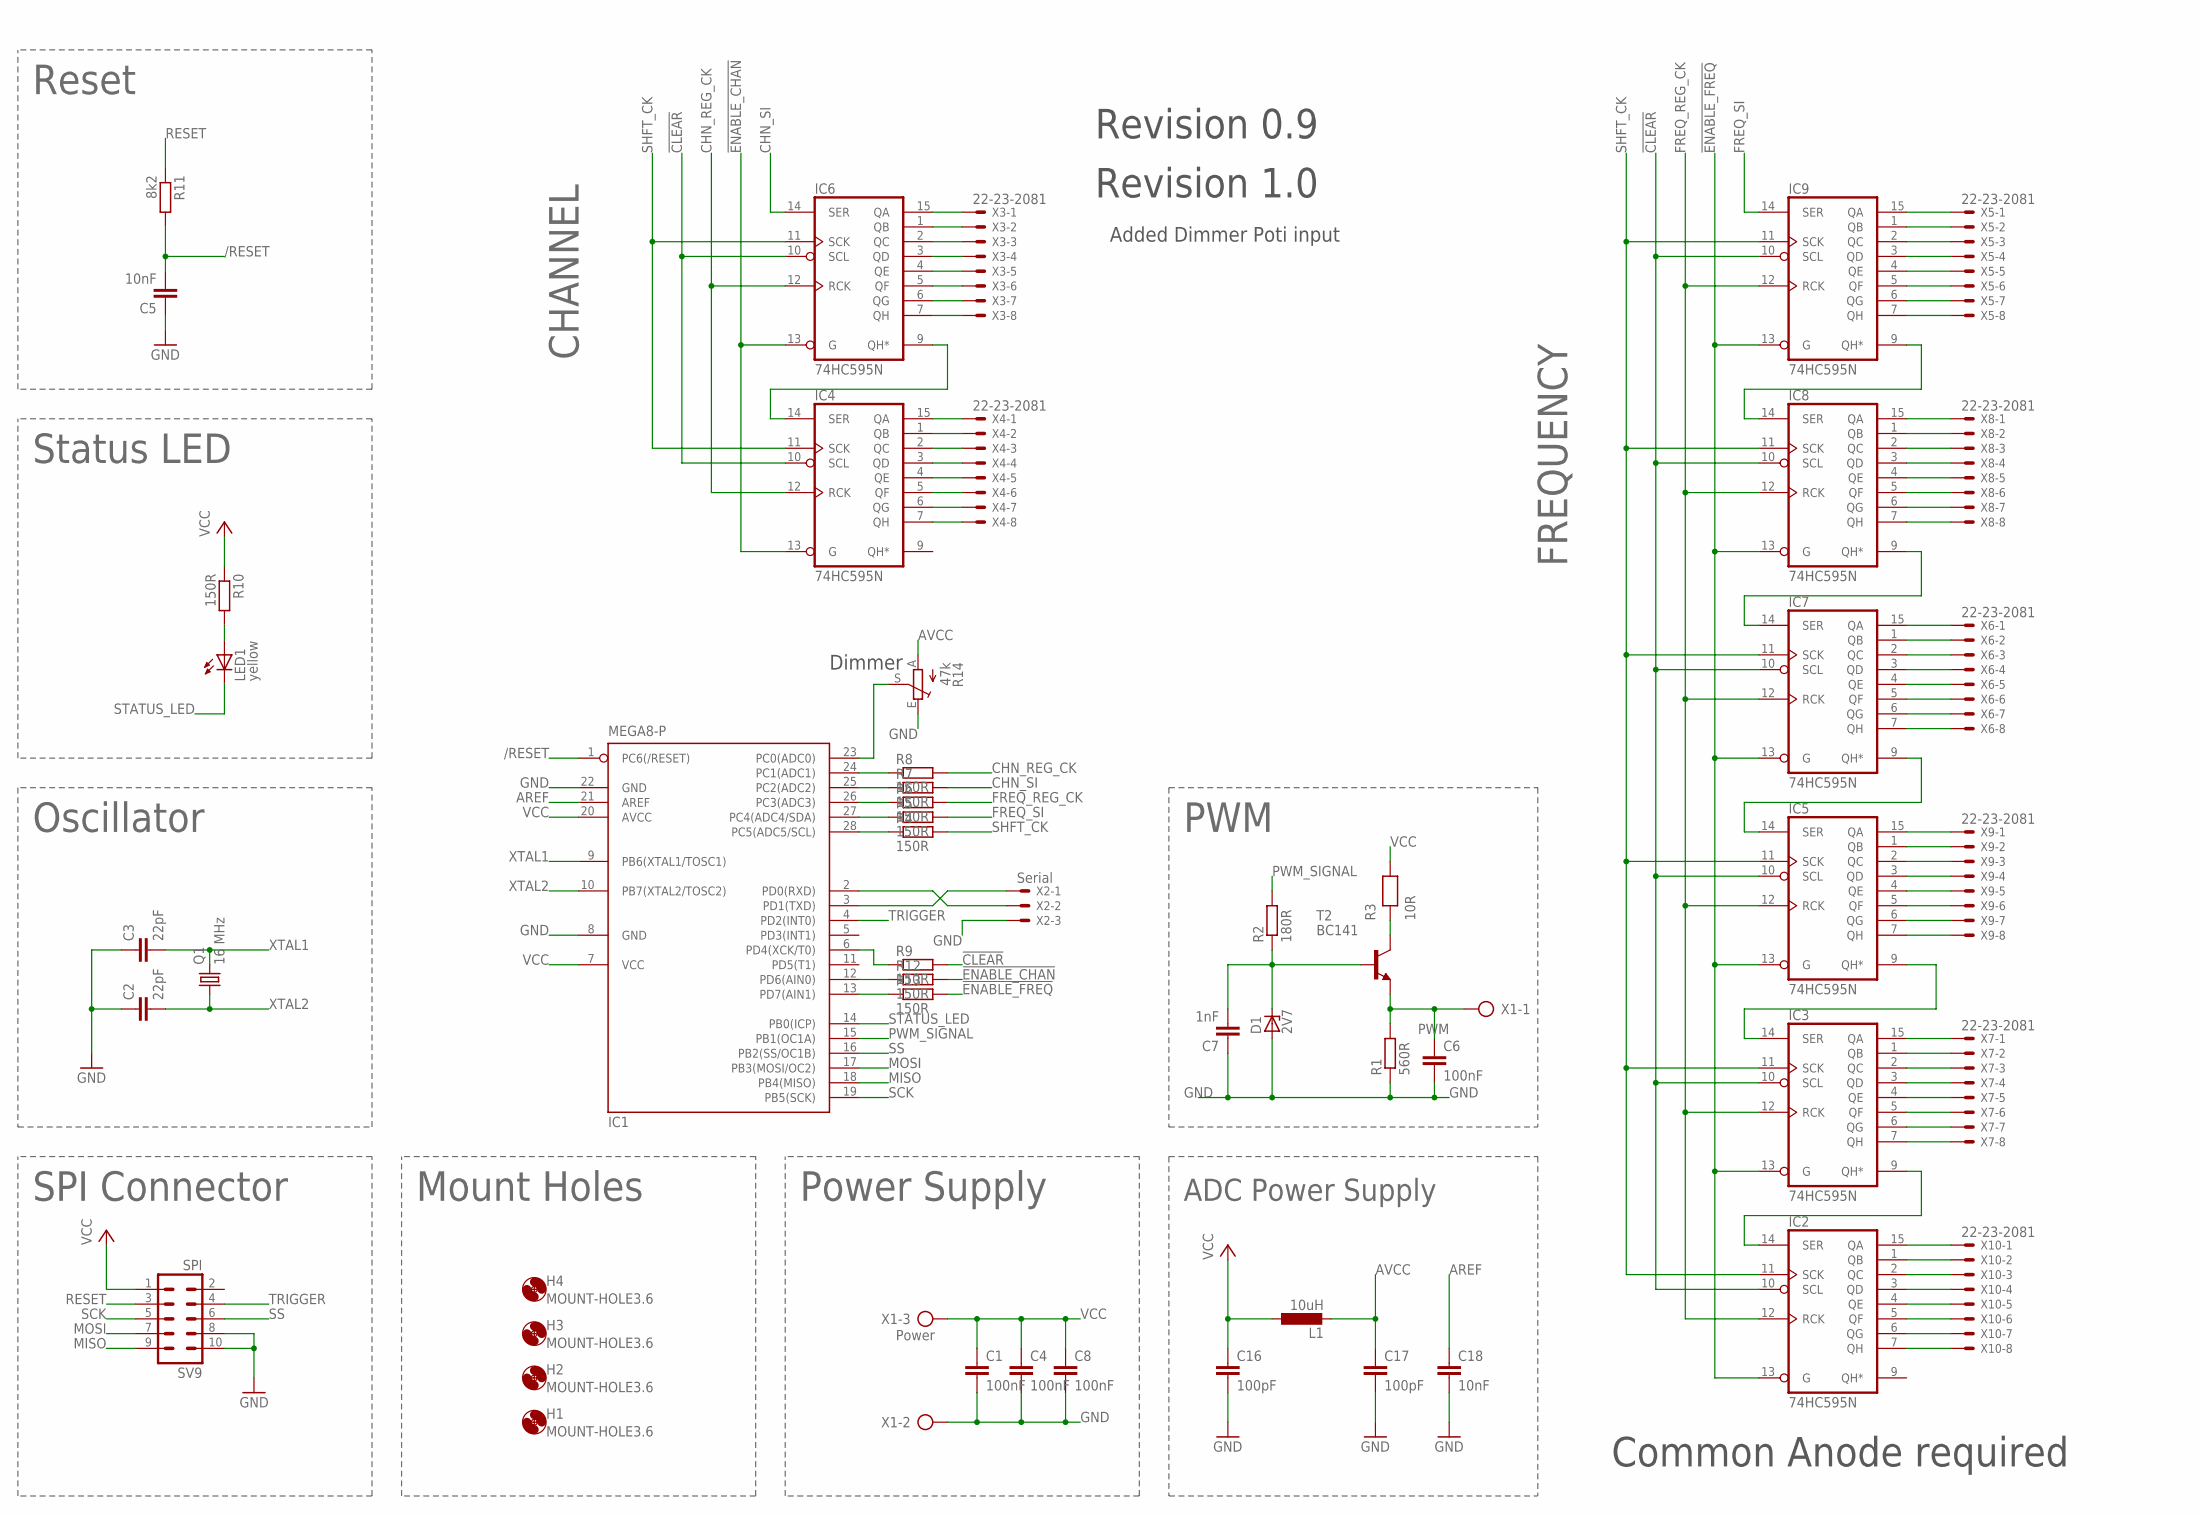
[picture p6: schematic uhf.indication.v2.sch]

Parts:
C1, C4, C6, C8: 100nF; C050-024X044
C2, C3: 22pF; C025-025X050
C5, C18: 10nF; C025-025X050
C7: 1nF; C025-025X050
C16, C17: 100pF; C025-025X050
D1: 2V7; ZDIO-10
H1, H2, H3, H4: MOUNT-HOLE3.6; 3,6
IC1: MEGA8-P; DIL28-3
IC2, IC3, IC4, IC5, IC6, IC7, IC8, IC9: 74HC595N; DIL16
L1: 10uH; 2200-15.24
LED1: yellow; CHIPLED_1206
Q1: 16 MHz; HC18U-V
R1: 560R; 0207/2V@1
R2: 180R; 0207/2V@1
R3: 10R; 208-08
R4, R5, R6, R7, R8, R9, R10, R12, R13: 150R; R0805
R11: 8k2; M0805
R14: 47k; B25V
SV9: SPI; ML10
T2: BC141; TO39
X1: Power; AK500/3
X2: Serial; 22-23-2031
X3, X4, X5, X6, X7, X8, X9, X10: 22-23-2081

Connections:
!CLEAR: IC2.10 (SCL), IC3.10 (SCL), IC4.10 (SCL), IC5.10 (SCL), IC6.10 (SCL), IC7.10 (SCL), IC8.10 (SCL), IC9.10 (SCL), R9.2
!ENABLE_CHAN: IC4.13 (G), IC6.13 (G), R12.2
!ENABLE_FREQ: IC2.13 (G), IC3.13 (G), IC5.13 (G), IC7.13 (G), IC8.13 (G), IC9.13 (G), R13.2
/RESET: C5.2, IC1.1 (PC6(/RESET)), R11.2
AREF: C18.1, IC1.21 (AREF)
AVCC: C17.1, L1.2, R14.A
CHN_REG_CK: IC4.12 (RCK), IC6.12 (RCK), R8.2
CHN_SI: IC6.14 (SER), R7.2
FREQ_REG_CK: IC2.12 (RCK), IC3.12 (RCK), IC5.12 (RCK), IC7.12 (RCK), IC8.12 (RCK), IC9.12 (RCK), R6.2
FREQ_SI: IC9.14 (SER), R5.2
GND: C1.2, C2.1, C3.1, C4.2, C5.1, C6.2, C7.1, C8.2, C16.2, C17.2, C18.2, D1.A, IC1.8 (GND), IC1.22 (GND), IC2.8 (GND), IC3.8 (GND), IC4.8 (GND), IC5.8 (GND), IC6.8 (GND), IC7.8 (GND), IC8.8 (GND), IC9.8 (GND), R1.1, R14.E, SV9.8, SV9.10, X1.2, X2.3
MISO: IC1.18 (PB4(MISO)), SV9.9
MOSI: IC1.17 (PB3(MOSI/OC2)), SV9.7
unnamed: IC1.28 (PC5(ADC5/SCL)), R4.1
unnamed: IC1.6 (PD4(XCK/T0)), R9.1
unnamed: IC4.14 (SER), IC6.9 (QH*)
unnamed: IC6.15 (QA), X3.1
unnamed: IC1.24 (PC1(ADC1)), R8.1
unnamed: IC1.25 (PC2(ADC2)), R7.1
unnamed: IC8.14 (SER), IC9.9 (QH*)
unnamed: IC7.14 (SER), IC8.9 (QH*)
unnamed: IC5.14 (SER), IC7.9 (QH*)
unnamed: IC3.14 (SER), IC5.9 (QH*)
unnamed: IC2.14 (SER), IC3.9 (QH*)
unnamed: IC6.1 (QB), X3.2
unnamed: IC6.2 (QC), X3.3
unnamed: IC6.3 (QD), X3.4
unnamed: IC6.4 (QE), X3.5
unnamed: IC6.5 (QF), X3.6
unnamed: IC6.6 (QG), X3.7
unnamed: IC6.7 (QH), X3.8
unnamed: IC4.15 (QA), X4.1
unnamed: IC4.1 (QB), X4.2
unnamed: IC4.2 (QC), X4.3
unnamed: IC4.3 (QD), X4.4
unnamed: IC4.4 (QE), X4.5
unnamed: IC4.5 (QF), X4.6
unnamed: IC4.6 (QG), X4.7
unnamed: IC4.7 (QH), X4.8
unnamed: IC9.15 (QA), X5.1
unnamed: IC9.1 (QB), X5.2
unnamed: IC9.2 (QC), X5.3
unnamed: IC9.3 (QD), X5.4
unnamed: IC9.4 (QE), X5.5
unnamed: IC1.26 (PC3(ADC3)), R6.1
unnamed: IC1.27 (PC4(ADC4/SDA)), R5.1
unnamed: IC9.5 (QF), X5.6
unnamed: IC9.6 (QG), X5.7
unnamed: C7.2, D1.C, R2.1, T2.2 (B)
unnamed: R3.P$2, T2.3 (C)
unnamed: IC1.13 (PD7(AIN1)), R13.1
unnamed: IC1.12 (PD6(AIN0)), R12.1
unnamed: IC1.23 (PC0(ADC0)), R14.S
unnamed: IC9.7 (QH), X5.8
unnamed: IC8.15 (QA), X8.1
unnamed: LED1.A, R10.2
unnamed: IC8.1 (QB), X8.2
unnamed: IC8.2 (QC), X8.3
unnamed: IC8.3 (QD), X8.4
unnamed: IC8.4 (QE), X8.5
unnamed: IC8.5 (QF), X8.6
unnamed: IC8.6 (QG), X8.7
unnamed: IC8.7 (QH), X8.8
unnamed: IC7.15 (QA), X6.1
unnamed: IC7.1 (QB), X6.2
unnamed: IC7.2 (QC), X6.3
unnamed: IC7.3 (QD), X6.4
unnamed: IC7.4 (QE), X6.5
unnamed: IC7.5 (QF), X6.6
unnamed: IC7.6 (QG), X6.7
unnamed: IC7.7 (QH), X6.8
unnamed: IC5.15 (QA), X9.1
unnamed: IC5.1 (QB), X9.2
unnamed: IC5.2 (QC), X9.3
unnamed: IC5.3 (QD), X9.4
unnamed: IC5.4 (QE), X9.5
unnamed: IC5.5 (QF), X9.6
unnamed: IC5.6 (QG), X9.7
unnamed: IC5.7 (QH), X9.8
unnamed: IC3.15 (QA), X7.1
unnamed: IC3.1 (QB), X7.2
unnamed: IC3.2 (QC), X7.3
unnamed: IC3.3 (QD), X7.4
unnamed: IC3.4 (QE), X7.5
unnamed: IC3.5 (QF), X7.6
unnamed: IC3.6 (QG), X7.7
unnamed: IC3.7 (QH), X7.8
unnamed: IC2.15 (QA), X10.1
unnamed: IC2.1 (QB), X10.2
unnamed: IC2.2 (QC), X10.3
unnamed: IC2.3 (QD), X10.4
unnamed: IC2.4 (QE), X10.5
unnamed: IC2.5 (QF), X10.6
unnamed: IC2.6 (QG), X10.7
unnamed: IC2.7 (QH), X10.8
PWM: C6.1, R1.2, T2.1 (E), X1.1
PWM_SIGNAL: IC1.15 (PB1(OC1A)), R2.2
RESET: R11.1, SV9.3
RX: IC1.2 (PD0(RXD)), X2.2
SCK: IC1.19 (PB5(SCK)), SV9.5
SHFT_CK: IC2.11 (SCK), IC3.11 (SCK), IC4.11 (SCK), IC5.11 (SCK), IC6.11 (SCK), IC7.11 (SCK), IC8.11 (SCK), IC9.11 (SCK), R4.2
SS: IC1.16 (PB2(SS/OC1B)), SV9.6
STATUS_LED: IC1.14 (PB0(ICP)), LED1.C
TRIGGER: IC1.4 (PD2(INT0)), SV9.4
TX: IC1.3 (PD1(TXD)), X2.1
VCC: C1.1, C4.1, C8.1, C16.1, IC1.7 (VCC), IC1.20 (AVCC), IC2.16 (VCC), IC3.16 (VCC), IC4.16 (VCC), IC5.16 (VCC), IC6.16 (VCC), IC7.16 (VCC), IC8.16 (VCC), IC9.16 (VCC), L1.1, R3.P$1, R10.1, SV9.1, X1.3
XTAL1: C3.2, IC1.9 (PB6(XTAL1/TOSC1)), Q1.2
XTAL2: C2.2, IC1.10 (PB7(XTAL2/TOSC2)), Q1.1

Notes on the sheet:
SPI Connector
Mount Holes
Oscillator
Status LED
Reset
Power Supply
CHANNEL
FREQUENCY
Common Anode required
PWM
Revision 0.9
Revision 1.0
Added Dimmer Poti input
ADC Power Supply
Dimmer

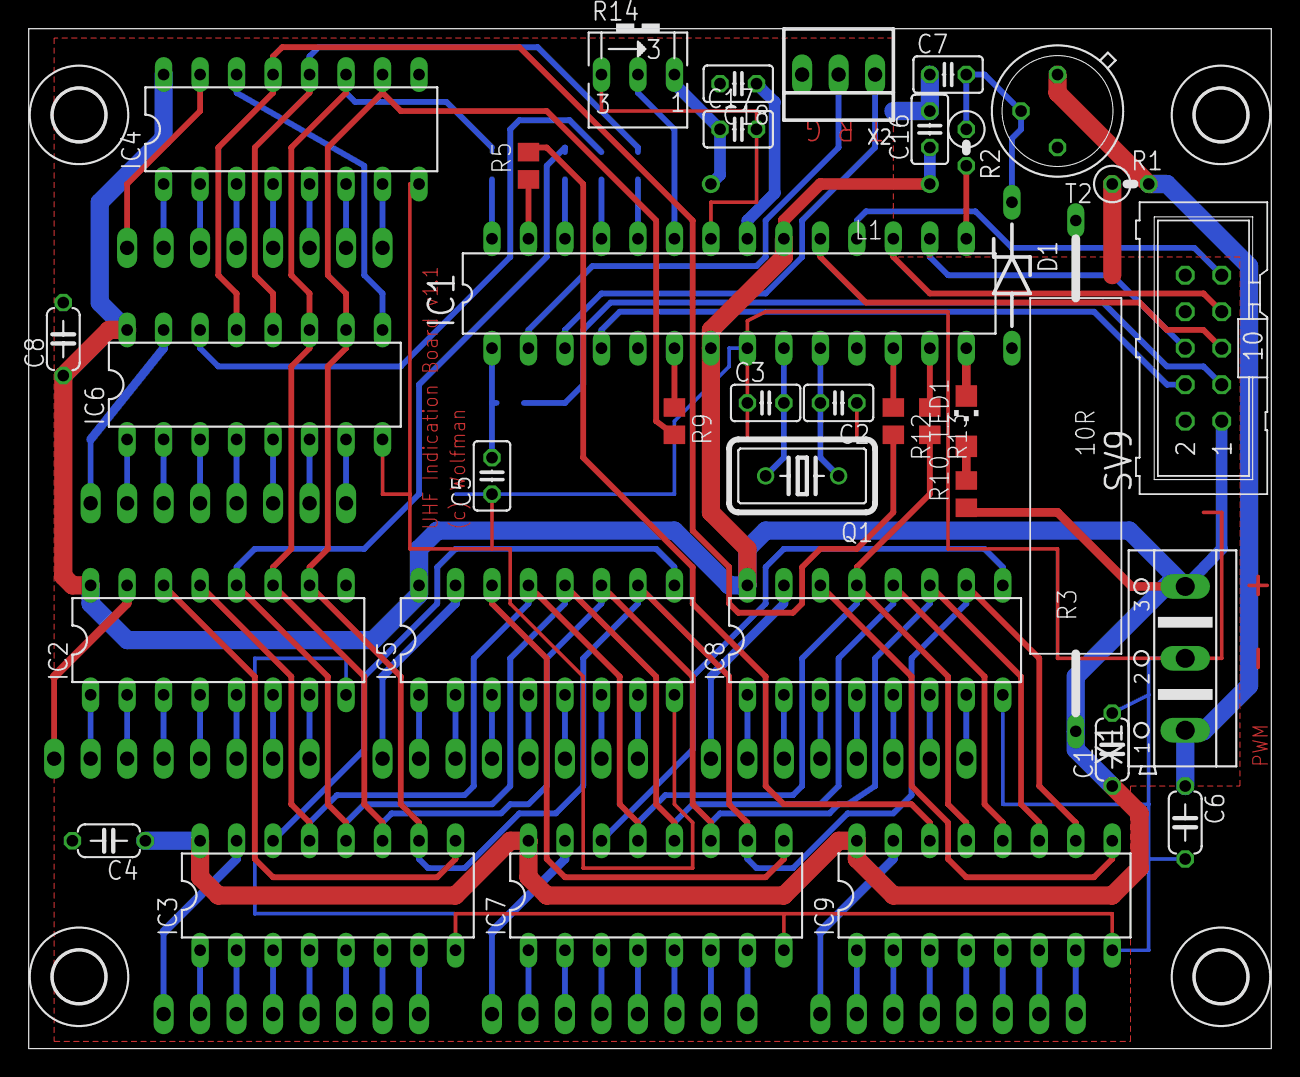
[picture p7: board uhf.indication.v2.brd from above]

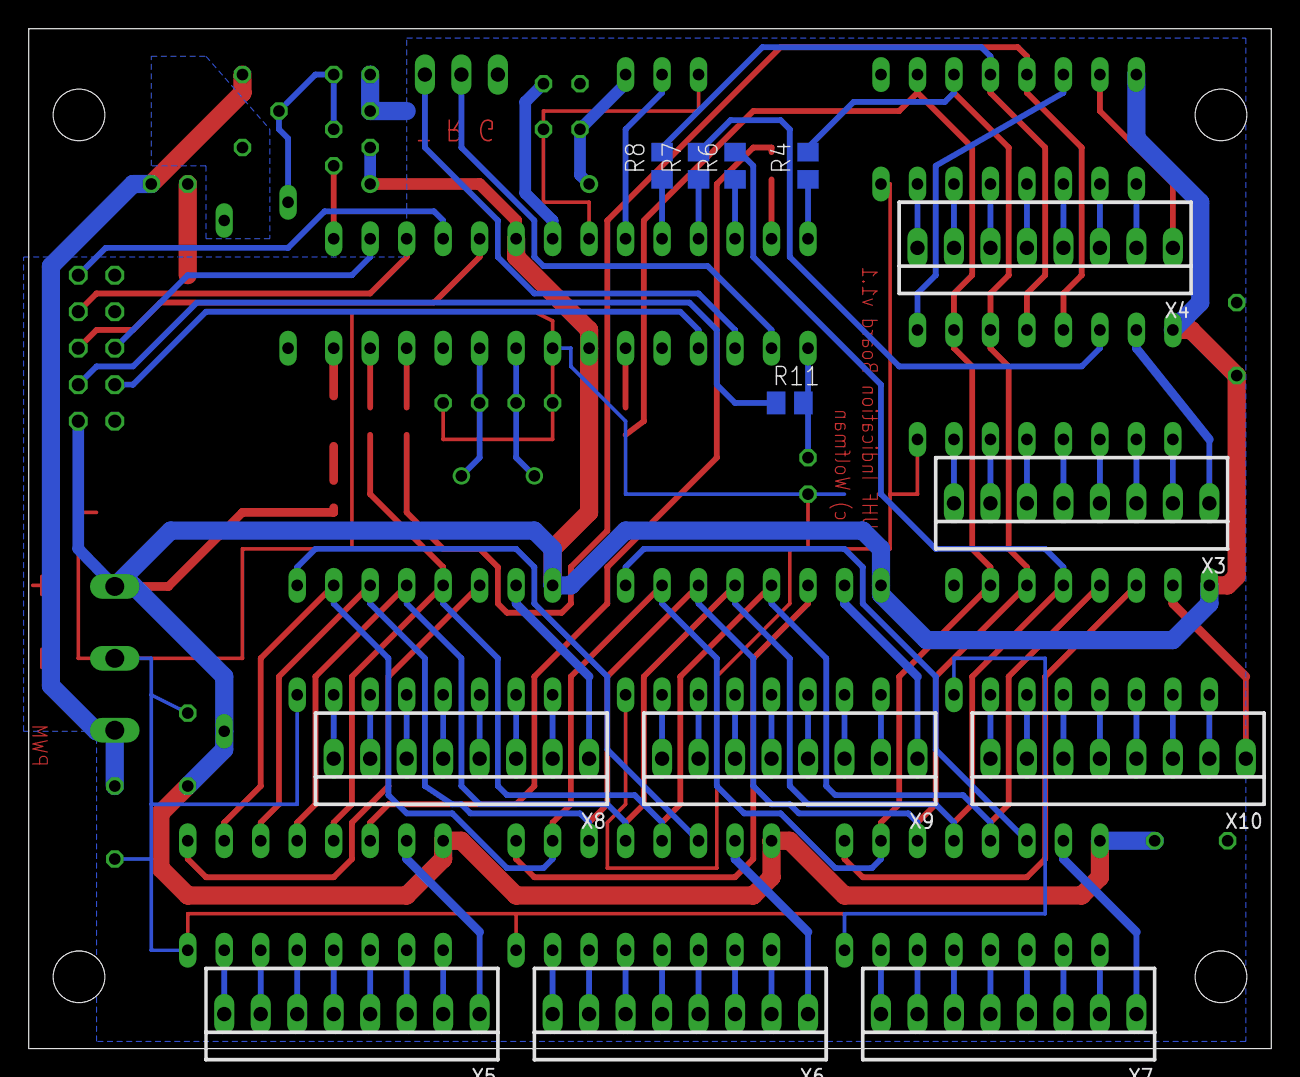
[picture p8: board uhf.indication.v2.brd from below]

Board: 2 copper layers, 86.5 x 71.0 mm, 54 parts (13 on the bottom side), 108 nets.

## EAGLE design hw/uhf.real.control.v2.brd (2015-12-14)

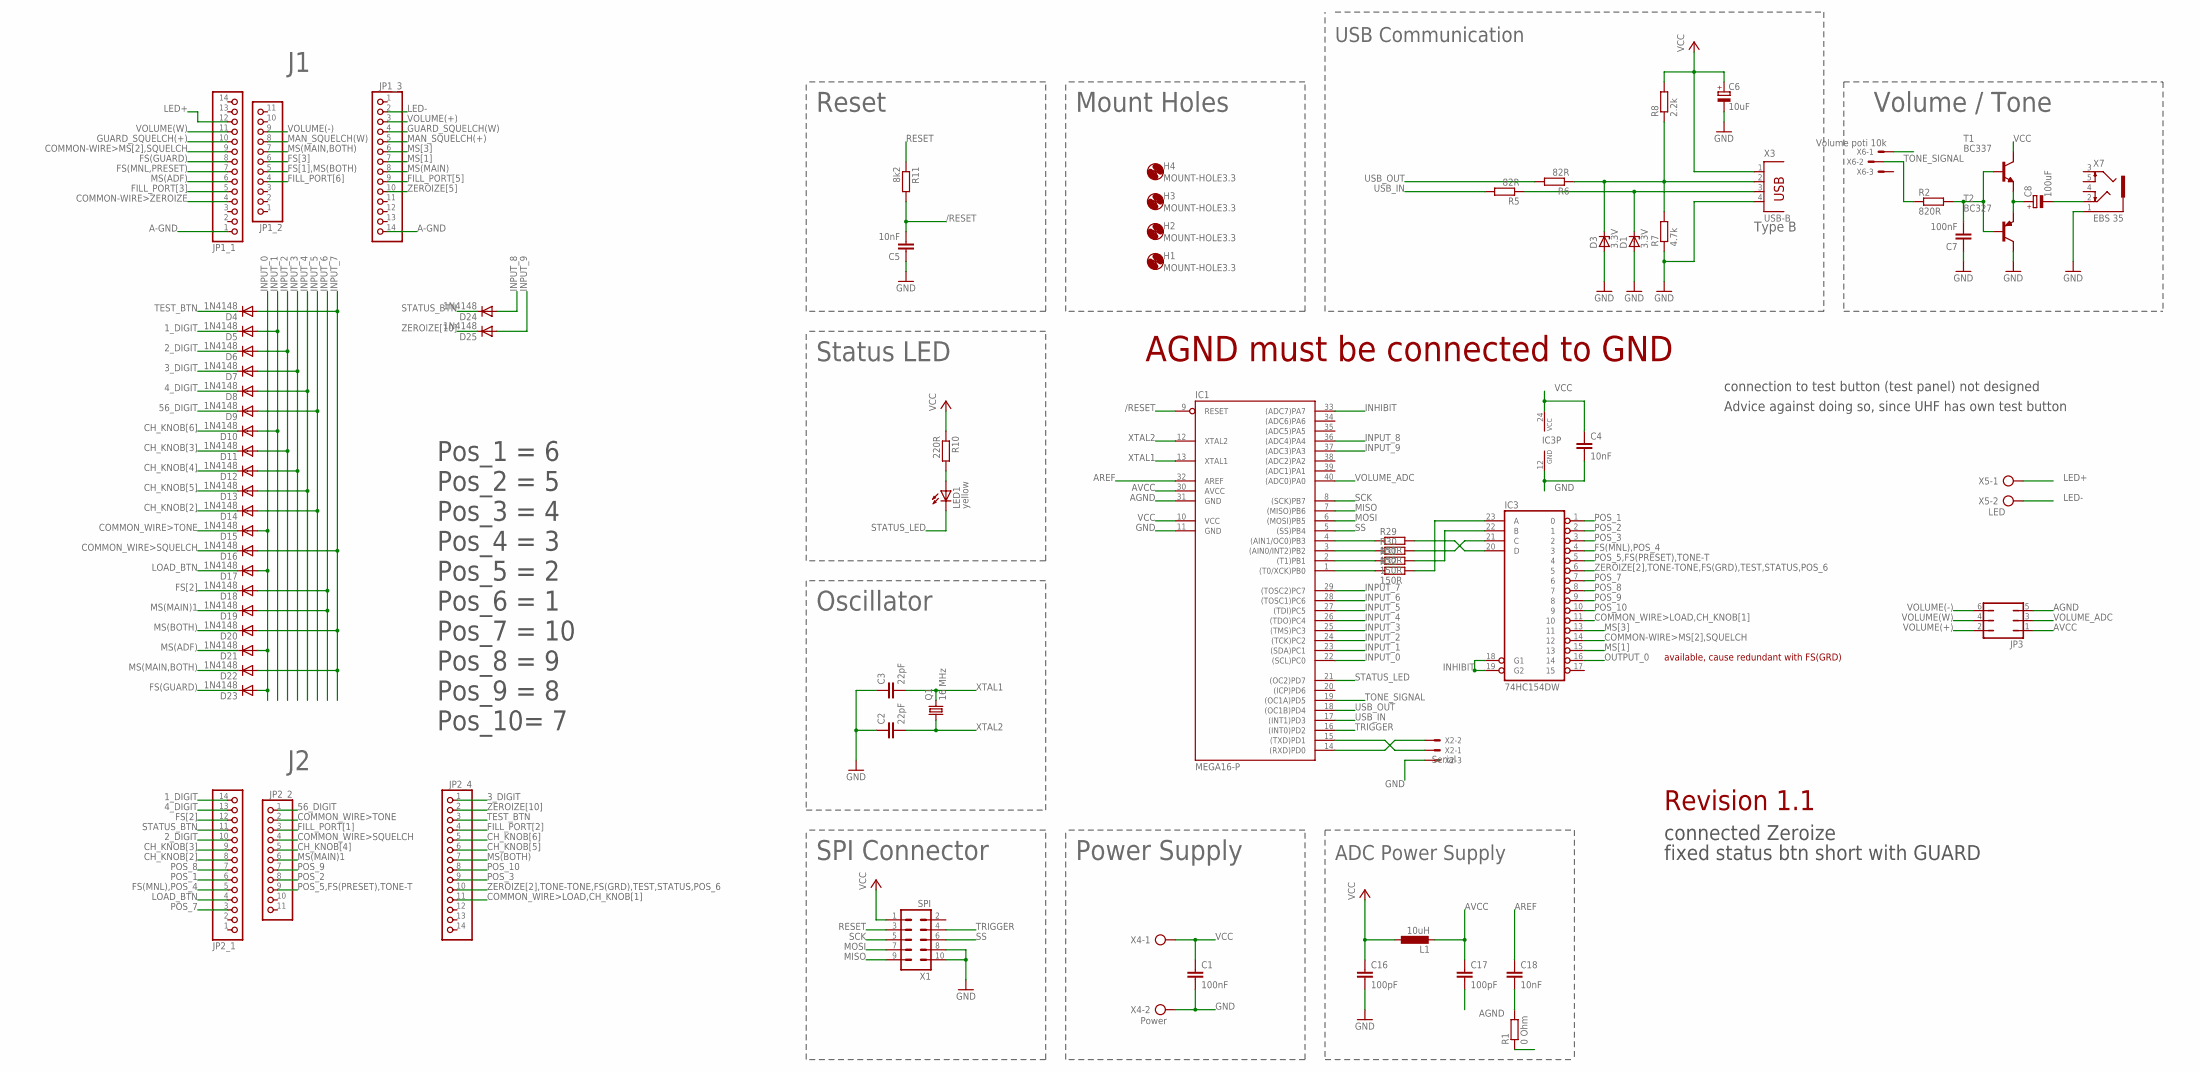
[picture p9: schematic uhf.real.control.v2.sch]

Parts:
C1, C7: 100nF; C050-024X044
C2, C3: 22pF; C025-025X050
C4, C5, C18: 10nF; C025-025X050
C6: 10uF; E2,5-6
C8: 100uF; E2,5-6
C16, C17: 100pF; C025-025X050
D1, D3: 3.3V; DO35Z10
D4, D5, D6, D7, D8, D9, D10, D11, D12, D13, D14, D15, D16, D17, D18, D19, D20, D21, D22, D23, D24, D25: 1N4148; MINIMELF
H1, H2, H3, H4: MOUNT-HOLE3.3; 3,3
IC1: MEGA16-P; DIL40
IC3: 74HC154DW; SO24W
JP1_1, JP1_3, JP2_1, JP2_4: PINHD-1X14; 1X14
JP1_2, JP2_2: PINHD-1X11; 1X11
JP3: JP3Q
L1: 10uH; 2200-15.24
LED1: yellow; CHIPLED_1206
Q1: 16 MHz; HC18U-V
R1: 0 Ohm; R0805
R2: 820R; 0207/12
R5, R6: 82R; R0805
R7: 4.7k; R0805
R8: 2.2k; R0805
R10: 220R; R0805
R11: 8k2; M0805
R29, R30, R31, R32: 150R; M0805
T1: BC337; TO92-EBC
T2: BC327; TO92-EBC
X1: SPI; ML10
X2: Serial; 22-23-2031
X3: USB-B; PN61729
X4: Power; AK500/2
X5: LED; AK500/2
X6: Volume poti 10k; 22-23-2031
X7: EBS 35; 1503_09

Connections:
1_DIGIT: D5.C, JP2_1.14
2_DIGIT: D6.C, JP2_1.10
3_DIGIT: D7.C, JP2_4.1
4_DIGIT: D8.C, JP2_1.13
56_DIGIT: D9.C, JP2_2.1
/RESET: C5.2, IC1.9 (RESET), R11.2
A-GND: JP1_1.1, JP1_3.14
AGND: C17.2, C18.2, IC1.31 (GND), JP3.5, R1.2
AREF: C18.1, IC1.32 (AREF)
AVCC: C17.1, IC1.30 (AVCC), JP3.1, L1.2
CH_KNOB[2]: D14.C, JP2_1.8
CH_KNOB[3]: D11.C, JP2_1.9
CH_KNOB[4]: D12.C, JP2_2.5
CH_KNOB[5]: D13.C, JP2_4.6
CH_KNOB[6]: D10.C, JP2_4.5
COMMON-WIRE>MS[2],SQUELCH: IC3.14 (12), JP1_1.9
COMMON-WIRE>ZEROIZE: JP1_1.4
COMMON_WIRE>LOAD,CH_KNOB[1]: IC3.11 (10), JP2_4.11
COMMON_WIRE>SQUELCH: D16.C, JP2_2.4
COMMON_WIRE>TONE: D15.C, JP2_2.2
FILL_PORT[1]: JP2_2.3
FILL_PORT[2]: JP2_4.4
FILL_PORT[3]: JP1_1.5
FILL_PORT[5]: JP1_3.9
FILL_PORT[6]: JP1_2.4
FS(GUARD): D23.C, JP1_1.8
FS(MNL),POS_4: IC3.4 (3), JP2_1.5
FS(MNL,PRESET): JP1_1.7
FS[1],MS(BOTH): JP1_2.5
FS[2]: D18.C, JP2_1.12
FS[3]: JP1_2.6
GND: C1.2, C2.1, C3.1, C4.2, C5.1, C6.-, C7.1, C16.2, D1.A, D3.A, IC1.11 (GND), IC3.12 (GND), R1.1, R7.1, T2.C, X1.8, X1.10, X2.3, X3.4, X4.2, X7.1
GUARD_SQUELCH(+): JP1_1.10
GUARD_SQUELCH(W): JP1_3.4
IN: D1.C, R5.1, X3.3
INHIBIT: IC1.33 ((ADC7)PA7), IC3.18 (G1), IC3.19 (G2)
INPUT_0: D15.A, D17.A, D21.A, D23.A, IC1.22 ((SCL)PC0)
INPUT_1: D5.A, D10.A, IC1.23 ((SDA)PC1)
INPUT_2: D6.A, D11.A, IC1.24 ((TCK)PC2)
INPUT_3: D7.A, D12.A, IC1.25 ((TMS)PC3)
INPUT_4: D8.A, D13.A, IC1.26 ((TDO)PC4)
INPUT_5: D9.A, D14.A, IC1.27 ((TDI)PC5)
INPUT_6: D18.A, D19.A, IC1.28 ((TOSC1)PC6)
INPUT_7: D4.A, D16.A, D20.A, D22.A, IC1.29 ((TOSC2)PC7)
INPUT_8: D24.A, IC1.36 ((ADC4)PA4)
INPUT_9: D25.A, IC1.37 ((ADC3)PA3)
LED+: JP1_1.12, X5.1
LED-: JP1_3.2, X5.2
LOAD_BTN: D17.C, JP2_1.4
MAN_SQUELCH(+): JP1_3.5
MAN_SQUELCH(W): JP1_2.8
MISO: IC1.7 ((MISO)PB6), X1.9
MOSI: IC1.6 ((MOSI)PB5), X1.7
MS(ADF): D21.C, JP1_1.6
MS(BOTH): D20.C, JP2_4.7
MS(MAIN): JP1_3.8
MS(MAIN)1: D19.C, JP2_2.6
MS(MAIN,BOTH): D22.C, JP1_2.7
MS[1]: IC3.15 (13), JP1_3.7
MS[3]: IC3.13 (11), JP1_3.6
unnamed: IC3.23 (A), R32.2
unnamed: C7.2, R2.2, T1.B, T2.B
unnamed: IC3.22 (B), R31.2
unnamed: IC3.21 (C), R30.2
unnamed: C8.+, T1.E, T2.E
unnamed: C8.-, X7.2
unnamed: IC3.20 (D), R29.2
unnamed: IC1.4 ((AIN1/OC0)PB3), R29.1
unnamed: IC1.3 ((AIN0/INT2)PB2), R30.1
unnamed: IC1.2 ((T1)PB1), R31.1
unnamed: IC1.1 ((T0/XCK)PB0), R32.1
unnamed: R2.1, X6.2
unnamed: LED1.A, R10.2
OUT: D3.C, R6.1, R7.2, R8.1, X3.2
OUTPUT_0: IC3.16 (14)
POS_1: IC3.1 (0), JP2_1.6
POS_2: IC3.2 (1), JP2_2.8
POS_3: IC3.3 (2), JP2_4.9
POS_5,FS(PRESET),TONE-T: IC3.5 (4), JP2_2.9
POS_7: IC3.7 (6), JP2_1.3
POS_8: IC3.8 (7), JP2_1.7
POS_9: IC3.9 (8), JP2_2.7
POS_10: IC3.10 (9), JP2_4.8
RESET: R11.1, X1.3
RX: IC1.14 ((RXD)PD0), X2.2
SCK: IC1.8 ((SCK)PB7), X1.5
SS: IC1.5 ((SS)PB4), X1.6
STATUS_BTN: D24.C, JP2_1.11
STATUS_LED: IC1.21 ((OC2)PD7), LED1.C
TEST_BTN: D4.C, JP2_4.3
TONE_SIGNAL: IC1.19 ((OC1A)PD5), X6.1
TRIGGER: IC1.16 ((INT0)PD2), X1.4
TX: IC1.15 ((TXD)PD1), X2.1
USB_IN: IC1.17 ((INT1)PD3), R5.2
USB_OUT: IC1.18 ((OC1B)PD4), R6.2
VCC: C1.1, C4.1, C6.+, C16.1, IC1.10 (VCC), IC3.24 (VCC), L1.1, R8.2, R10.1, T1.C, X1.1, X3.1, X4.1
VOLUME(+): JP1_3.3, JP3.2
VOLUME(-): JP1_2.9, JP3.6
VOLUME(W): JP1_1.11, JP3.4
VOLUME_ADC: IC1.40 ((ADC0)PA0), JP3.3
XTAL1: C3.2, IC1.13 (XTAL1), Q1.2
XTAL2: C2.2, IC1.12 (XTAL2), Q1.1
ZEROIZE[2],TONE-TONE,FS(GRD),TEST,STATUS,POS_6: IC3.6 (5), JP2_4.10
ZEROIZE[5]: JP1_3.10
ZEROIZE[10]: D25.C, JP2_4.2

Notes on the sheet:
SPI Connector
Mount Holes
Oscillator
Status LED
Reset
Power Supply
USB Communication
Type B
Volume / Tone
ADC Power Supply
Pos_1 = 6
Pos_2 = 5
Pos_3 = 4
Pos_4 = 3
Pos_5 = 2
Pos_6 = 1
Pos_7 = 10
Pos_8 = 9
Pos_9 = 8
Pos_10= 7
connected Zeroize
AGND must be connected to GND
connection to test button (test panel) not designed
Advice against doing so, since UHF has own test button
Revision 1.1
fixed status btn short with GUARD
available, cause redundant with FS(GRD)

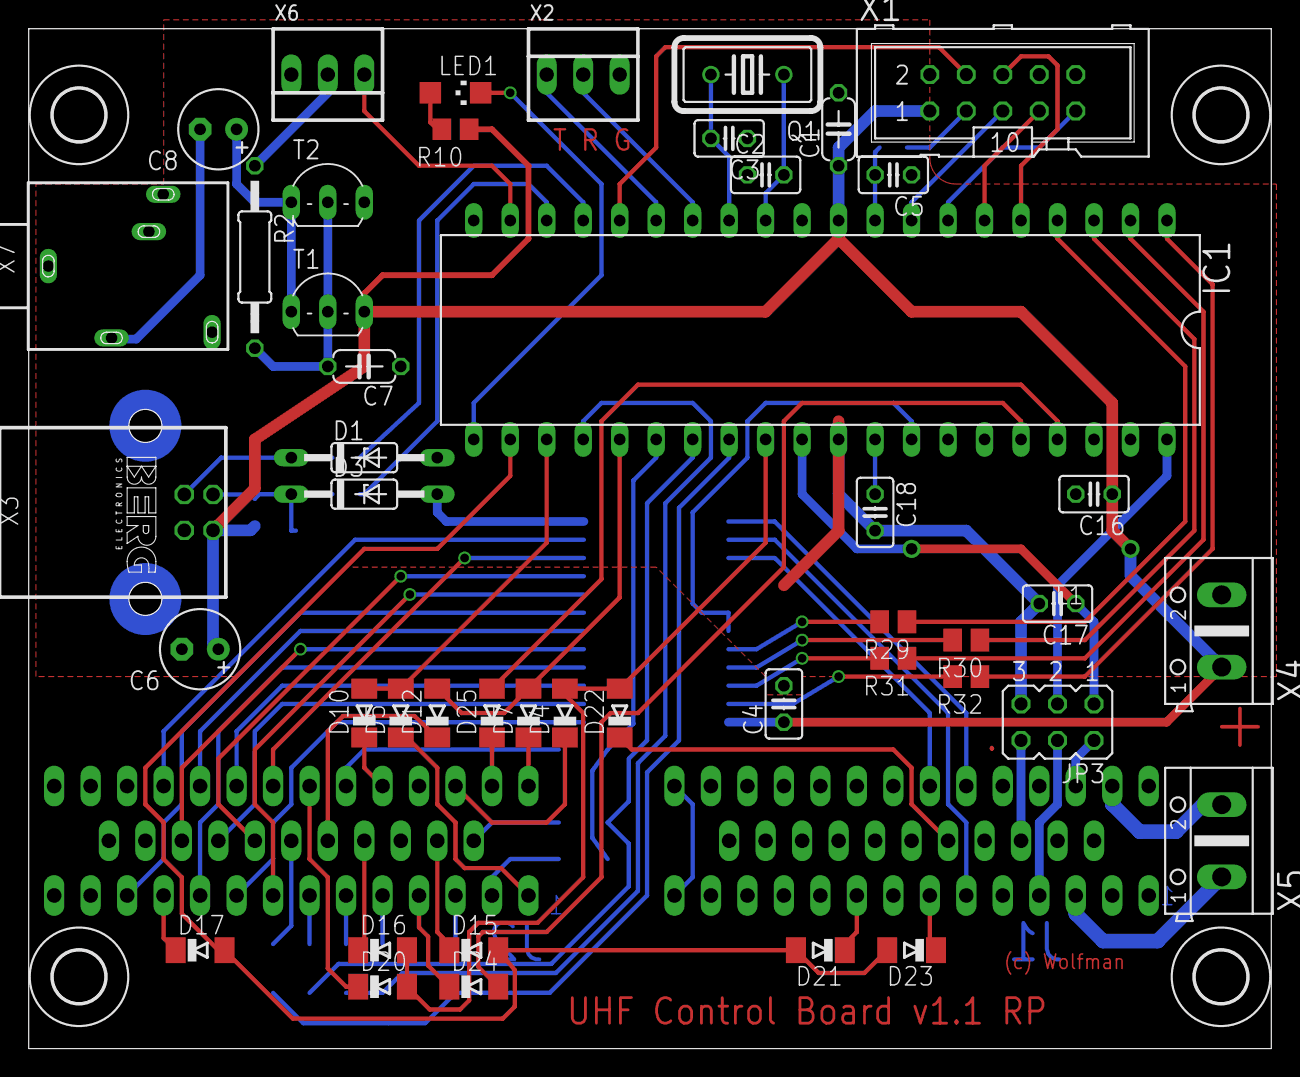
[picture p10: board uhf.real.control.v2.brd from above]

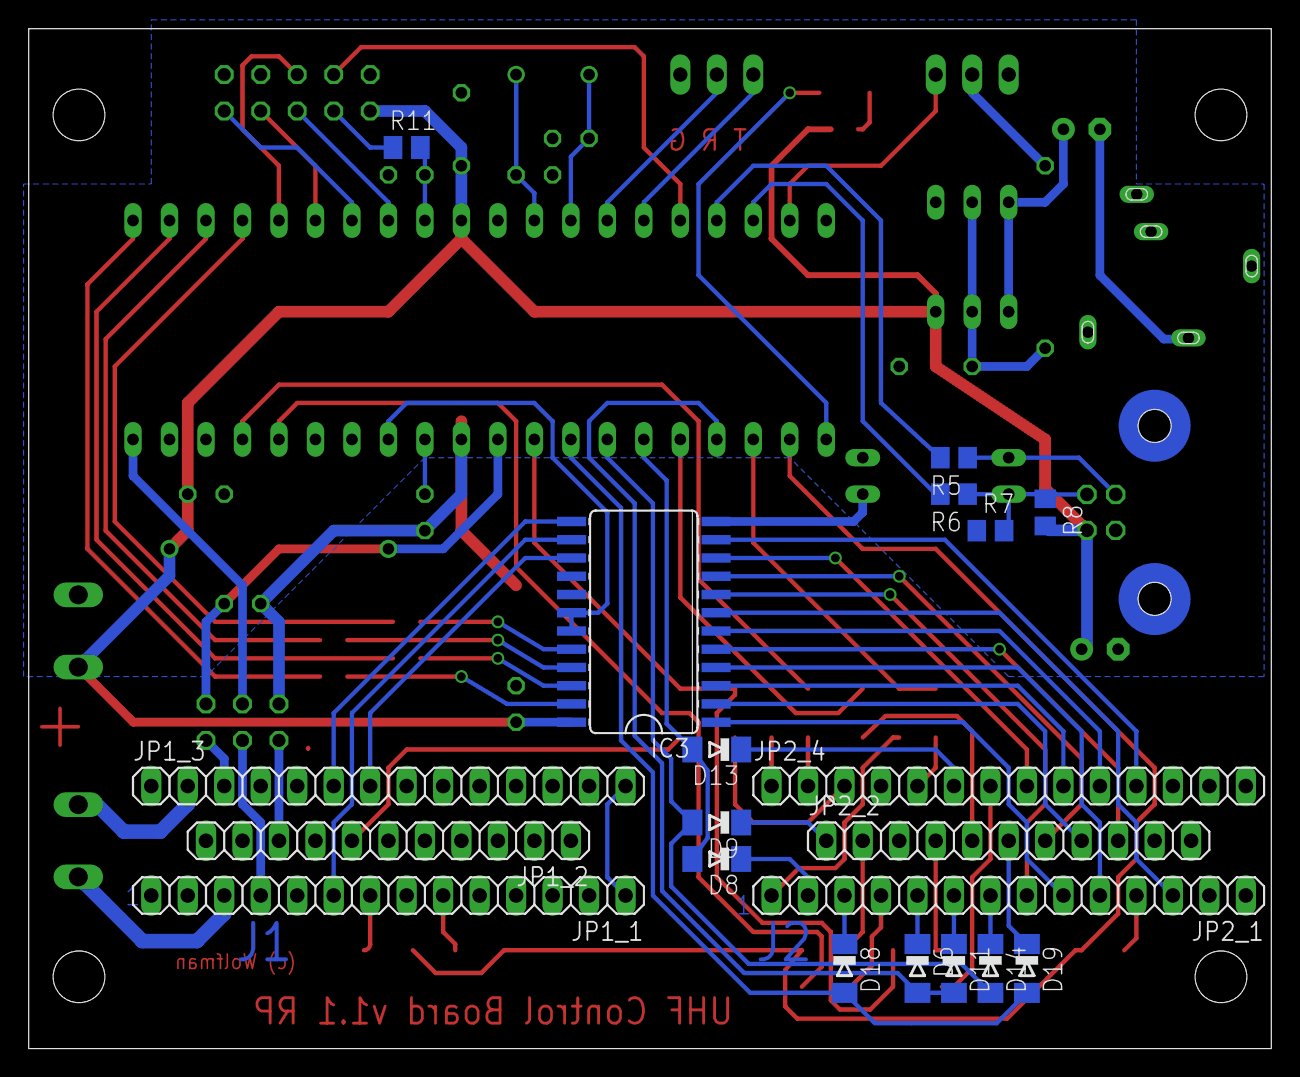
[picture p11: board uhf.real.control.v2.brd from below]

Board: 2 copper layers, 86.5 x 71.0 mm, 71 parts (20 on the bottom side), 89 nets.

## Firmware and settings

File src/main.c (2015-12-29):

/*
 * main.c
 *
 *  Created on: 16.04.2011
 *      Author: Wolfgang Engelhard
 *
 * Copyright: (c) 2011 by Wolfgang Engelhard
 * License: GNU GPL v2 (see License.txt)
 */

#include <inttypes.h>
#include <avr/io.h>
#include <avr/pgmspace.h>
#include <avr/eeprom.h>
#include <avr/interrupt.h>
#include <avr/sleep.h>
#include <avr/wdt.h>
#include <util/delay.h>

#include "main.h"
#include "uhf.h"
#include "key.h"
#include "spi.h"
#include "serial.h"
#include "timer.h"
#include "debug.h"
#include "terminal.h"
#include "usb.h"
#include "usbKeyDefs.h"

/****************************   FLASH CONSTANTS       ************************/
const uint8_t sReady[] PROGMEM =
"\033c\nAN/ARC-164 UHF IIa Airborne Radio ready...\r\n\033[s\0";

/****************************   FUNCTION DECLARATIONS ************************/
/**
 * Port pin assignment for UHF Control Board RP v1.0
 * PORTA
 * 0: Volume ADC (ADC0)
 * 1..2 N/C
 * 3: Input 9
 * 4: Input 8
 * 5: N/C
 * 6: Output 0
 * 7: Inhibit IC 154 (inhibit on H)
 * PORTB
 * 0: A
 * 1: B
 * 2: C
 * 3: D
 * 4: SPI SS
 * 5: SPI MOSI
 * 6: SPI MISO
 * 7: SPI CLK
 * PORTC
 * 0..7: Input 0..7
 * PORTD
 * 0: RX
 * 1: TX
 * 2: Trigger (INT0)
 * 3: USB_IN
 * 4: USB_OUT
 * 5: Tone_waveout (OC1A)
 * 6: N/C
 * 7: Status LED (OC2)
 */
void initIO() {

  DDRA = (1 << PIN_INHIBIT | 1 << PIN_OUTPUT_0);
  PORTA = (1 << PIN_INHIBIT | 1 << INPUT8 | 1 << INPUT9);

  DDRB = (1 << SPI_MOSI | 1 << SPI_SCK | 1 << SPI_SS);
  DDRB |= 0x0F;             // IC 154 A..D
  PORTB &= ~(1 << SPI_SS);  // pull low to indicate presence of control board

  // enable internal pull up
  PORTC = 0xFF;

  setStatusLedOn();
  DDRD = (1 << PIN_UART_TX | 1 << PIN_WAVEOUT | 1 << PIN_LED);
  PORTD = (1 << USB_CFG_DMINUS_BIT | 1 << USB_CFG_DPLUS_BIT);
  DDRD |= (1 << USB_CFG_DMINUS_BIT | 1 << USB_CFG_DPLUS_BIT);
  /* USB reset of a single ended device needs both lines pulled high for at least 10 ms */
  _delay_ms(15);
  /* remove USB reset condition */
  DDRD = (1 << PIN_UART_TX | 1 << PIN_WAVEOUT | 1 << PIN_LED);
  PORTD = (1 << USB_CFG_DMINUS_BIT); /* USB low speed device must hold D- (only) high (shouldn't be necessary since hw does pull up)*/
  // status led is on
  setStatusLedOff();
}

/**
 * enable multiplexer IC 74 HC 154
 */
void initMultiplexer() {
                                    // active when low
  PORTA &= ~(1 << PIN_INHIBIT);     // set multiplexer device active
  PORTA &= ~(1 << PIN_OUTPUT_0);    // output for additional keys set low
}

/**
 * main function
 */
int main(void) {
  uint8_t row = 0;
  uint8_t row2 = 0;

  wdt_enable(WDTO_2S);

  initIO();

  if (initSerial()) {
    TCCR2 |= (1 << WGM20 | 1 << COM21 | 1 << COM20);/* error */
    OCR2 = 16;                                      /* show by LED blinking */
    for (;;) {
      ;
    }
  }

  initSpi();

  initTimer();

  initMultiplexer();

  initUsb();

  set_sleep_mode(SLEEP_MODE_IDLE);

#if DEBUG_LEVEL > 0
  debugFlag.keyPoll = FALSE;
  debugFlag.pwm = FALSE;
  debugFlag.pollChannel = FALSE;
  debugFlag.readChannel = FALSE;
#endif

  sendUartString_P((uint8_t*) sReady);
  storeCursor();

  PORTD &= ~(1 << USB_CFG_DMINUS_BIT); /* reset D- to default state */
  setStatusLedOn();
  sei();

  // set default values
  initVariables();

  for (;;) {

    wdt_reset();
    usbPoll();

    /* USB SECTION -------------------------------------------------*/
    /* releases key press */
    sendUsbMessage(NOT_USED);
    /* USB SECTION -------------------------------------------------*/

    if (serialStatus.rx) {
      serialStatus.rx = 0;
      DBG(rxValue);
    }

#if DEBUG_LEVEL > 0
    if (debugFlag.keyPoll) {

      if (row++ > 15) {
        row = 0;
        restoreCursor();
      } else {
        sendUartBitPattern(PINC);
        if (row == KEY_ADD_ROW + 1) {
          sendUartByte('\t');
          sendUartBitPattern(PINA);
        }
      }
      sendUartHex(row);
      sendUartByte(' ');
      PORTB &= 0xF0;
      PORTB |= row;
      PORTA &= 0x18;
      PORTA |= row2;
      setStatusLedOn();
    } else
#endif

    // query Keys
    if (keyState.readKeys) {
      readChannel();
      readKeys();
      readAdditionalKeys();
    }

    //setState();
    processChannel();
    processInputData(get_key_short(ALL_KEYS));

    if (uhfControl.resend && (uhfControl.test != TRUE)) {
      if (uhfKeyState.FUSEL == FS_GUARD) {
        setGuard();
      }

      uhfControl.resend = FALSE;
      if (uhfKeyState.OFF != MS_OFF) {
        if (uhfControl.firstRun) {
          uhfControl.firstRun = FALSE;
          setUhfOn();
        }
#ifdef deactivated
        if(uhfOpMode == FMTCHG && uhfControl.fmtTimeout) {
          sendData(getChannelString(), (uint8_t*)"FMTCHG");
        } else
#endif
        sendData(getChannelString(), getFrequencyString());
      }
    }

    if (usbInterruptIsReady()) {
      isUsbPresent = TRUE;
    }

  } /* endless loop */

  return 0;
}

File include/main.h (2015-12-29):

/*
 * main.h
 *
 *  Created on: 16.04.2011
 *      Author: Wolfgang Engelhard
 *
 * Copyright: (c) 2011 by Wolfgang Engelhard
 * License: GNU GPL v2 (see License.txt)
 */

#ifndef MAIN_H_
#define MAIN_H_

#include <avr/io.h>

/****************************   DEFINITIONS           ************************/
#define TRUE    1
#define FALSE   0

#define STATUS_LED_PORT PORTD
#define MULTIPLEXPORT   PORTB

#define PIN_INHIBIT     PORTA7
#define PIN_OUTPUT_0    PORTA6
#define PIN_WAVEOUT     PORTD5
#define PIN_LED         PORTD7
#define PIN_UART_TX     PORTD1
#define PIN_TRIGGER     PORTD2
#define SPI_MOSI        PORTB5
#define SPI_SCK         PORTB7
#define SPI_SS          PORTB4

/****************************   INLINE FUNCTIONS      ************************/
static inline void setStatusLedOff(void) {
  STATUS_LED_PORT |= (1 << PIN_LED);
}

static inline void setStatusLedOn(void) {
  STATUS_LED_PORT &= ~(1 << PIN_LED);
}

#endif /* MAIN_H_ */

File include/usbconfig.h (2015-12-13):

/* Name: usbconfig.h
 * Project: V-USB, virtual USB port for Atmel's(r) AVR(r) microcontrollers
 * Template Author: Christian Starkjohann
 * Author: Wolfgang Engelhard
 * Creation Date: 2011-10-06
 * Tabsize: 4
 * Copyright: (c) 2005 by OBJECTIVE DEVELOPMENT Software GmbH
 * License: GNU GPL v2 (see License.txt), GNU GPL v3 or proprietary (CommercialLicense.txt)
 * This Revision: $Id: usbconfig-prototype.h 785 2010-05-30 17:57:07Z cs $
 */

#ifndef __usbconfig_h_included__
#define __usbconfig_h_included__

/* ---------------------------- Custom definitions ------------------------- */
#define USB_DATA_TX         0x0D

/*
General Description:
This file is an example configuration (with inline documentation) for the USB
driver. It configures V-USB for USB D+ connected to Port D bit 2 (which is
also hardware interrupt 0 on many devices) and USB D- to Port D bit 4. You may
wire the lines to any other port, as long as D+ is also wired to INT0 (or any
other hardware interrupt, as long as it is the highest level interrupt, see
section at the end of this file).
+ To create your own usbconfig.h file, copy this file to your project's
+ firmware source directory) and rename it to "usbconfig.h".
+ Then edit it accordingly.
*/

/* ---------------------------- Hardware Config ---------------------------- */

#define USB_CFG_IOPORTNAME      D
/* This is the port where the USB bus is connected. When you configure it to
 * "B", the registers PORTB, PINB and DDRB will be used.
 */
#define USB_CFG_DMINUS_BIT      4
/* This is the bit number in USB_CFG_IOPORT where the USB D- line is connected.
 * This may be any bit in the port.
 */
#define USB_CFG_DPLUS_BIT       3
/* This is the bit number in USB_CFG_IOPORT where the USB D+ line is connected.
 * This may be any bit in the port. Please note that D+ must also be connected
 * to interrupt pin INT0! [You can also use other interrupts, see section
 * "Optional MCU Description" below, or you can connect D- to the interrupt, as
 * it is required if you use the USB_COUNT_SOF feature. If you use D- for the
 * interrupt, the USB interrupt will also be triggered at Start-Of-Frame
 * markers every millisecond.]
 */
#define USB_CFG_CLOCK_KHZ 16000
//(F_CPU/1000)
/* Clock rate of the AVR in kHz. Legal values are 12000, 12800, 15000, 16000,
 * 16500, 18000 and 20000. The 12.8 MHz and 16.5 MHz versions of the code
 * require no crystal, they tolerate +/- 1% deviation from the nominal
 * frequency. All other rates require a precision of 2000 ppm and thus a
 * crystal!
 * Since F_CPU should be defined to your actual clock rate anyway, you should
 * not need to modify this setting.
 */
#define USB_CFG_CHECK_CRC       0
/* Define this to 1 if you want that the driver checks integrity of incoming
 * data packets (CRC checks). CRC checks cost quite a bit of code size and are
 * currently only available for 18 MHz crystal clock. You must choose
 * USB_CFG_CLOCK_KHZ = 18000 if you enable this option.
 */

/* ----------------------- Optional Hardware Config ------------------------ */

/* #define USB_CFG_PULLUP_IOPORTNAME   D */
/* If you connect the 1.5k pullup resistor from D- to a port pin instead of
 * V+, you can connect and disconnect the device from firmware by calling
 * the macros usbDeviceConnect() and usbDeviceDisconnect() (see usbdrv.h).
 * This constant defines the port on which the pullup resistor is connected.
 */
/* #define USB_CFG_PULLUP_BIT          4 */
/* This constant defines the bit number in USB_CFG_PULLUP_IOPORT (defined
 * above) where the 1.5k pullup resistor is connected. See description
 * above for details.
 */

/* --------------------------- Functional Range ---------------------------- */
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

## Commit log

2015-12-14 re-added documentation and eagle brd files
    [uhf.indication.olimex.brd, uhf.indication.v2.brd, uhf.real.control.olimex.brd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]
2015-12-14 added firmware files for indication board
2015-12-30 added bom errata
2016-04-10 added implementation to send preset frequencies via usb
    usb message protocol now supports preset frequencies (0xEE)
    fixed FMT NET eeprom write
    [uhf.h, uhfProcessor.c]
2018-12-29 added schematics for board files
    [uhf.indication.v2.sch, uhf.real.control.v2.sch]
2019-04-29 update and fix of mapped keys send to PC. Synced with BMS 4.34.
2021-03-07 Update of keys to BMS 4.35 U1
2021-03-07 replaced incorrect .hex file with current version v28
